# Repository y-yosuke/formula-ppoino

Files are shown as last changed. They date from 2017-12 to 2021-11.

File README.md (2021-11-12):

# formula-ppoino
- 2000年代前半ぐらいのフォーミュラカーっぽい2人乗りのクルマ
- A side-by-side two-seater car of the early 2000s formula style

# License
- クリエイティブ・コモンズ 4.0（表示/ BY ）で公開・共有しています．[Creative Commons 4.0 (BY)](https://creativecommons.org/licenses/by/4.0/)



# Contact
- Email: ppoino.cars.yy[a-t]gmail.com

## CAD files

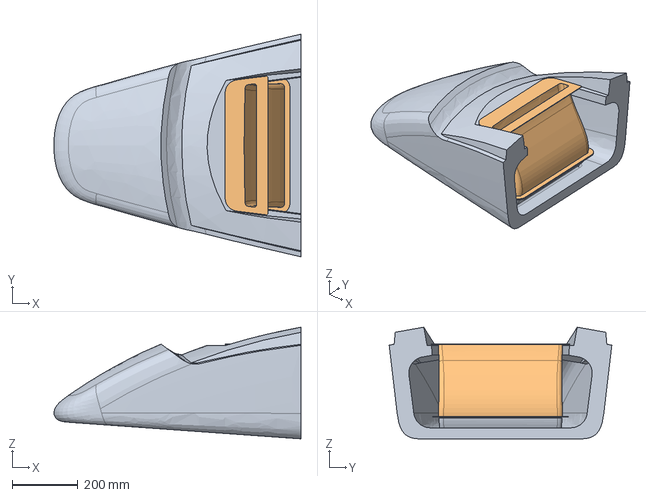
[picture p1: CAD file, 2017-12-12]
models/fp_nose_cone_assy.stp
749.1 x 675.3 x 338.7 mm

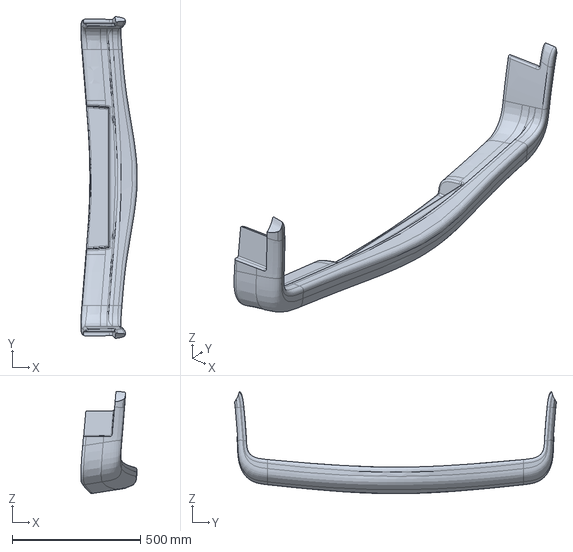
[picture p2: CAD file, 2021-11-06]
models/fp_rr_bumper.stp
220.4 x 1256.1 x 399.2 mm

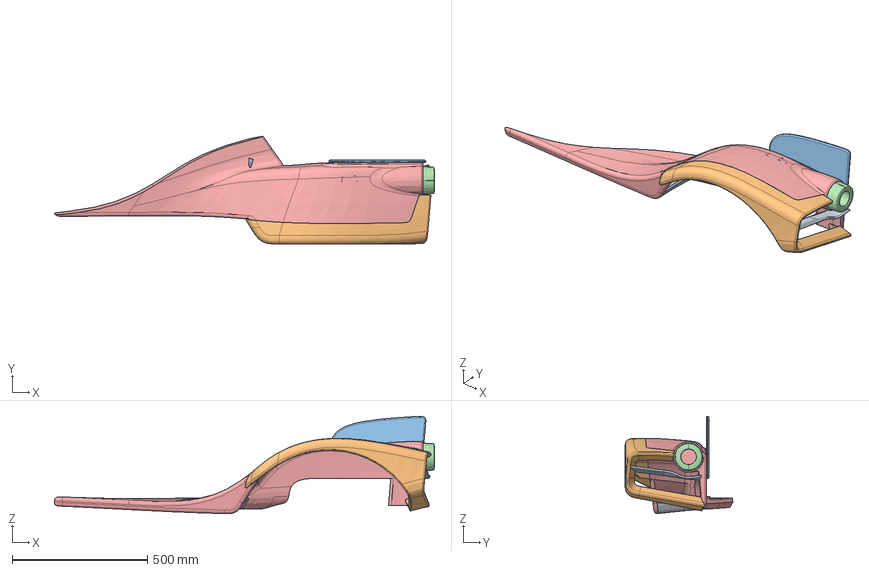
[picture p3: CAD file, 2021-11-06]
models/fp_rr_fender.stp
1404.7 x 398.4 x 359.8 mm

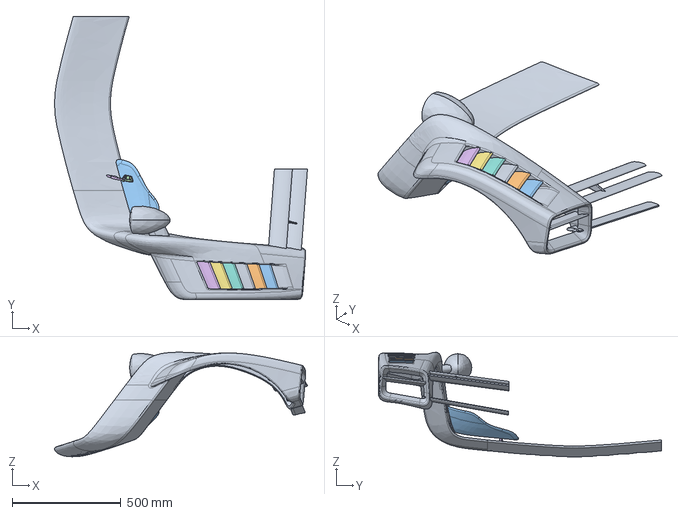
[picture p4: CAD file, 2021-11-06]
models/fp_fr_fender.stp
1161.1 x 1300.0 x 480.1 mm

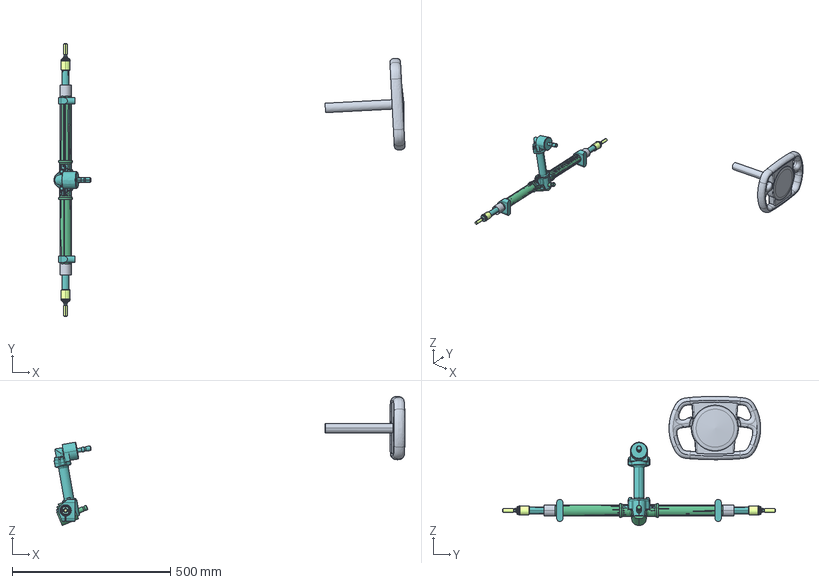
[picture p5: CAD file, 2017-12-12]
models/fp_steering_sys.stp
1108.2 x 862.0 x 407.7 mm

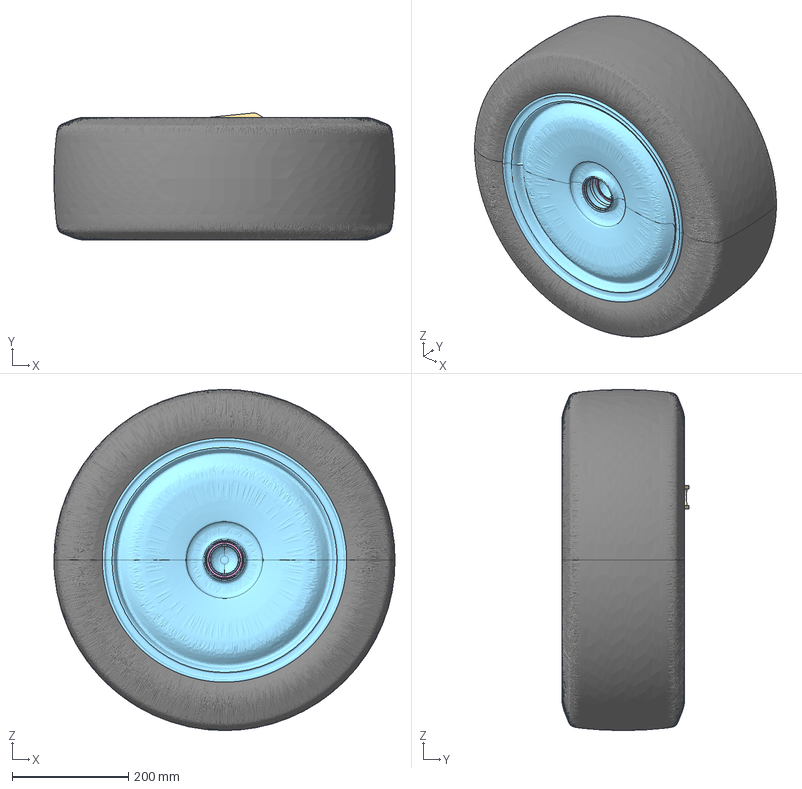
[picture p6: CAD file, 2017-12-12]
models/fp_fr_axle_sys.stp
586.7 x 218.5 x 587.0 mm

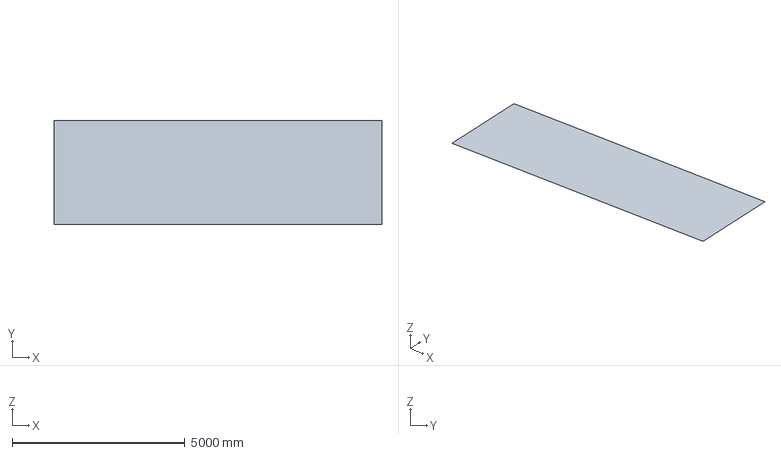
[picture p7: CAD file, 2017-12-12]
models/fp_environment.stp
9500.0 x 3000.0 x 0 mm

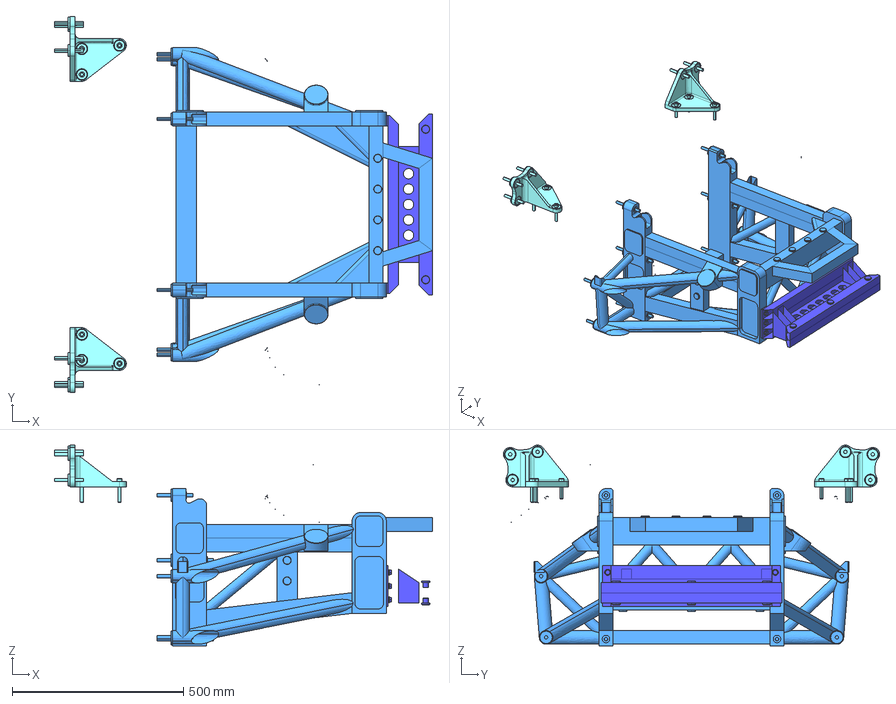
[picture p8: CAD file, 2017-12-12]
models/fp_rr_frame_sys.stp
1105.0 x 1100.0 x 587.0 mm

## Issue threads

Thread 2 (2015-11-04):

EV Module

y-yosuke, 2015-11-04:
ppoino-cars の formula-ppoino にある EV 関連の話のつづき．
https://github.com/y-yosuke/ppoino-cars/issues/4

y-yosuke, 2015-11-04:
formula-ppoino だけではなくて他の作りたいクルマでも利用できるものにしたい．

y-yosuke, 2015-11-11:
【メモ】
SiC半導体インバータの利点
https://www.youtube.com/watch?v=hzS-GOyyhTQ

y-yosuke, 2015-11-11:
【メモ】
Zytek Motors and Inverters / Mugen Honda CR-Z?
http://www.zytekautomotive.co.uk/products/electric-engines/
（あまり仕様的にはフィットしなそうだけど...）

y-yosuke, 2015-11-11:
おっと，YASA Motors に新しい P400 という製品が加わっている．
http://www.yasamotors.com/products/
http://www.yasamotors.com/products/p400_series/

y-yosuke, 2015-11-11:
YASA Motors - Patent Drawings
http://www.google.com/patents/US20130147291

y-yosuke, 2015-11-25:
【メモ】
乗用車やバスなどの商用車のモータ・インバータ・ビークルコントロールユニット
http://tm4.com/products/

y-yosuke, 2015-11-25:
【メモ】
シーメンス Siemens - SIVETEC モータ・インバータ・コントロールユニット
http://w3.siemens.com/topics/global/en/electromobility/Pages/powertrain-ecar.aspx

y-yosuke, 2015-11-25:
Tesla Roadster のバッテリー構造
http://www.teslamotorsclub.com/showthread.php/3810-Roadster-battery-%28ESS%29

y-yosuke, 2015-11-27:
理想的なインバータ・モータ統合モジュール
YASA 750 x2 x2 だったらこんな感じ．
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

y-yosuke, 2015-12-21:
Nissan Leaf NISMO RC が載っている MotorFan Illustrated Vol.58［Lite版］が ￥0 になってます．
http://3a.as-books.jp/books/info.php?no=MFI20110716
（紙版より企画を一部抜粋しての提供）

y-yosuke, 2015-12-24:
Formula-e - NEXTEV TCR Formula E 001 (2015-2016) に使われている？？？
http://www.gkn.com/driveline/our-solutions/edrive-systems/documents/datasheets/af-130-tech-sheet-v13.pdf

y-yosuke, 2015-12-24:
Formula-e のバッテリーは

容量 | 28kWh
----|----
出力 | 200kW
----|----
セル重量 | 200kg
----|----
バッテリーモジュール全体重量 | 345kg
とのこと．
「Motor Fan illustrated特別編集 Motorsportのテクノロジー 2015-2016 電子版」より
http://3a.as-books.jp/books/info.php?no=MFS20151224

y-yosuke, 2015-12-24:
Formula-e のバッテリーモジュール結構重いな．
あと F-1 もドライバ込み最低重量 702kg も今はあるのか... 500kg は遠き昔となりにけり．

emijah, 2016-01-08:
安全性に関してうるさくなりましたからね。重量をある程度上げないとドライバを守るのは難しいのかもしれませんね。

y-yosuke, 2016-01-08:
F1のレギュレーションの変遷のまとめを見ると
ざっくりと 620kg ぐらいまでは安全性の確保のため
700kg への変化は駆動系の複雑化のように見受けられます．
http://matome.naver.jp/odai/2134296850068589401

y-yosuke, 2016-01-08:
VW マイクロバスコンセプトカー BUDD-e
  - 蓄電容量101kWh
  - 4輪駆動
  - 最高速150km/h
  - 最大600kmの走行可能

http://response.jp/article/2016/01/06/267337.html

スペックは実走値なのか？ コンセプトとしてはこの値ということなのか？

y-yosuke, 2016-01-08:
Audi e-tron quattro concept

- 4輪適宜駆動
- 3モーター
  - 合計最大出力 370kW
  - 最大トルク 500Nm
- バッテリー容量 95kWh
- 最長航続距離 500km

http://car.watch.impress.co.jp/docs/event_repo/ces2016/20160108_738120.html

大きめの乗用車だと 100kW 前後が当たり前になってくるのかな．

emijah, 2016-01-13:
Teslaってスペック出ていますよね？ Xとかそれなりのモータが積まれていそう

y-yosuke, 2016-01-13:
https://en.wikipedia.org/wiki/Tesla_Model_X#Specifications

emijah, 2016-01-13:
３８６kWか568kWの２バージョンですね

y-yosuke, 2016-02-19:
日立造船 : 耐久性と安全性を向上させた全固体リチウムイオン二次電池を開発～低温から高温まで動作可能かつ長寿命～
http://www.hitachizosen.co.jp/news/2016/02/002027.html
（寸法と使用可能温度以外の仕様が発表されていない）

y-yosuke, 2016-02-20:
昨年の秋ぐらいに SiCインバータの回路モジュールのサンプル出荷が始まったはずなんだけど...
製品のカタチをなすのにはまだ時間がかかるということなのかな？
（続報はどこかにありましたか？？？）

y-yosuke, 2016-03-15:
【参考】Torque vectoring の話など
Mercedes SLS Electric Drive. Can Volts Ever Match Pistons? - /CHRIS HARRIS ON CARS
https://www.youtube.com/watch?v=IElqf-FCMs8

y-yosuke, 2016-03-18:
わーぉ Ariel Atom が電気自動車になっとるー
http://www.wrightspeed.com/about/x1/

y-yosuke, 2016-03-18:
drayson racing の YASA 750 は冷却の配管を削り物の部品で置き換えて高さを抑えている．
http://speedhunters-wp-production.s3.amazonaws.com/wp-content/uploads/2013/12/06200010/Drayson_Racing_Lola_EV-15-1200x800.jpg
http://www.speedhunters.com/2013/12/high-voltage-assault-battery/

y-yosuke, 2016-03-22:
超イオン伝導体を発見し全固体セラミックス電池を開発―高出力・大容量で次世代蓄電デバイスの最有力候補に― 東京工業大学
http://www.titech.ac.jp/news/2016/033800.html

emijah, 2016-03-22:
@y-yosuke 出てくるのに少なくとも５年かかりそうなんですかね？

y-yosuke, 2016-03-22:
「5年」というのはどこかに書いてありましたか？

emijah, 2016-03-23:
この記事はないですが、たいがい５〜１０年が多いので。探してみる必要がありますね。

y-yosuke, 2016-03-23:
YASA 750 2個使いだったら tm4 CO150シリーズ もありだな．
特にコネクタ類が1面だけに出ているのでレイアウト的に非常に助かる．
http://www.tm4.com/products/power-electronics/co150-traction-inverter/

（Rinehart Mosion Systems の PM100 や PM150 シリーズは端子などが3面から出ていて難儀）

y-yosuke, 2016-03-28:
【参考資料】
SIP（戦略的イノベーション創造プログラム）
次世代パワーエレクトロニクス（どこでもパワエレ機器で豊かな省エネ社会）
研究開発計画
http://www8.cao.go.jp/cstp/gaiyo/sip/keikaku/2_pawaere.pdf

y-yosuke, 2016-03-29:
全固体電池、10年飛び越し（2015.02.19の記事）
http://techon.nikkeibp.co.jp/article/MAG/20150205/402627/?rt=nocnt
Seeo社は "300Wh/kgの電池パックを2017年に出荷予定" / "350〜400Wh/Kgの実現にもメド" とのこと．

emijah, 2016-03-29:
500kmくらい走れないと遠出をする気にはあまりならないっすからね

y-yosuke, 2016-03-31:
【参考】日立造船が全固体リチウムイオン電池を開発、車載用に2020年に製品化
http://monoist.atmarkit.co.jp/mn/articles/1603/04/news052.html

y-yosuke, 2016-04-29:
電池だけでも 200kg ほどになりそうなバッテリーモジュールの設置に関して思案．

1. 単体で成立するバッテリーボックス（ストレスメンバー）に電池を組み込む
2. モノコック後部を長め（+250mm）にしてその中に直接何分割かした電池子モジュールを組み込む
3. モノコック後部を長め（+250mm）にしてさらにバッテリーボックスも単体モジュール化（非ストレスメンバー）

　　　＊下に各方式の長所・短所を列挙

今のところ私が一番良いと考えているのは 1. の

「単体で成立するバッテリーボックス（ストレスメンバー）に電池を組み込む」

が構成としてシンプルで他車種への応用が高く良いと思っていて，
それでレイアウト・設計を進めている．
（他車種への応用性の高さは妄想工学的に吉☆）

単体バッテリーボックス（ストレスメンバー）レイアウトの図
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

-----

1. 単体バッテリーボックス（ストレスメンバー）に電池を組み込み
  - 長所
    - EV後部駆動システムとして完全なモジュール化により他車種への応用がシンプルに
    - バッテリー不具合時にバッテリーボックス全体の交換が容易
  - 短所
    - バッテリーボックスにした場合にはそれも人間の乗る方のモノコックと同等の剛性・強度が必要となりコスト増
      - リチウムポリマー電池の事故時の発火の防止
      - ストレスメンバーとして
    - モノコックとリアフレームが直接締結されないことによる剛性低下

2. 長モノコック（+250mm）内に電池を直接設置
  - 長所
    - モノコックとリアフレームが直接締結されることによる剛性向上
    - モノコック構造体が1つで済むのでコスト減？
    - 重量最小？
  - 短所
    - 他車種にてこのシステムを利用しようとした場合に別途バッテリーの設置方法の設計が必要
    - 不具合時にバッテリーを交換するときに各バッテリ子モジュールを外す必要あり
      - 公道走るだけっだったらこれでも十分か？
      - レースに使うことを考えると不十分か？
    - モノコックが長くなることでラジエタパイプの通しどころの自由度が低い
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
y-yosuke, 2017-01-12:
Formula-e のバッテリーの生産元？
http://www.xaltenergy.com/index.php/industries/automotive-transportation.html

y-yosuke, 2017-01-12:
18650 Cells で Tesla Roadster 的レイアウトをしてみた．
一応，水冷パイプの空間も残しているつもりで 2540 cells になった．

- 諸元
  - 電圧 : 3.60V
  - 容量 : 3400mAh
  - 重量 : 48 g

とすると...

- 2540 x 3.6 [V] x 3.4 [Ah] = 31089.6 [Wh] = 31.1 [kWh]
- 2540 x 48 [g] = 121920 [g] = 122 [kg]

となる．円筒形の方がエネルギ密度が高いのか？ Cell を小さくするとエネルギ密度を高くできるのか？
また，バッテリボックスの形に合わせてレイアウトも可能なので，そう言ったところにも優位性がありそう．しかし組立は大変そう．

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

emijah, 2017-01-12:
組立やすさは、どういうバスバーを使って電力を外に出すかで決まりそうですね。

2017年1月12日 15:05 Yosuke Yamamoto <notifications@github.com>:

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

y-yosuke, 2017-01-12:
XALT Energy によると Formula-e は XALT 53Ah high energy (HE) lithium ion cells を使用しているとのこと．
http://www.xaltenergy.com/index.php/automotive-transportation.html
http://www.xaltenergy.com/index.php/solutions/technology/cells.html
http://www.xaltenergy.com/images/pdfs/datasheets/XE_Data_53HE_Updated.pdf

y-yosuke, 2017-01-12:
McLaren P1 のロウ付け（salt bath dip brazing）ものの Cell Module も凄いな．
http://www.invetr.com/control-and-electronics/energy-storage-system
http://www.invetr.com/uploads/2/1/8/2/21829402/1635370_orig.jpg

y-yosuke, 2017-01-12:
@emijah
Tesla Roadster は下記リンク先のポストにある画像のように Cell を Module 化しています．
Module 化した後は簡単ですが Module 化するところが大変そうです．
https://teslamotorsclub.com/tmc/threads/roadster-battery-ess.3810/#post-61701

y-yosuke, 2017-01-12:
Li-Ion だったらどれも同じようなものかな．
HV用ハイパワーとEV用ハイエナジーの違いぐらいか．
原理は一緒だしな．

y-yosuke, 2017-01-12:
http://kokam.com/cell/ も XALT と同じようなパウチを作っているようだけど同じような性能．

y-yosuke, 2017-01-12:
Samsung SDI や LG Chem はいろいろと使われているようだけど大口顧客相手でカスタマイズしているためかバッテリの仕様が出ていない．

y-yosuke, 2017-01-16:
ＥＶ・ＨＥＶ 駆動システム技術展
http://www.evjapan.jp/
2017年1月18日［水］～ 20日［金］ 10:00～18:00 (最終日のみ17時まで)

「フォーミュラE」用インバータ改良前後の2種を展示
http://www.rohm.co.jp/web/japan/carele

y-yosuke, 2017-01-16:
ロボデックスと同時開催とのこと．→ EV・HEV 駆動システム技術展

y-yosuke, 2017-02-03:
日刊工業新聞2017年2月2日 ショート・発火しにくい、リチウム電池。産総研が開発
http://newswitch.jp/p/7813
"医療機器に使うバッテリーなどへの応用が期待できる。企業と連携し、２０２０年頃までの実用化を目指す。"

y-yosuke, 2017-02-07:
[Topic] ホンダと日立オートモティブ、ＥＶモーターで新会社
http://www.nikkei.com/article/DGXLASDZ07H9D_X00C17A2MM0000/?dg=1&nf=1

y-yosuke, 2017-02-07:
Renault ZOE の Battery は LG Chem らしい．
http://insideevs.com/renault-zoe-r240-battery-capacity-23-3-kwh-usable-25-92-kwh-total/

y-yosuke, 2017-02-15:
Aston Martin AM-RB 001 to use Cosworth V12 and Ricardo gearbox
Partners for upcoming hypercar also include Multimac for the MonoCell and Rimac for hybrid batteries
http://www.autocar.co.uk/car-news/new-cars/aston-martin-am-rb-001-use-cosworth-v12-and-ricardo-gearbox

y-yosuke, 2017-03-31:
ＥＶ充電時間を３分の１に　チャデモ協議会、機器規格改定
http://www.sankeibiz.jp/business/news/170331/bsa1703310500003-n1.htm
"自動車メーカーが今後投入する高出力バッテリー搭載モデルで利用"

y-yosuke, 2017-04-04:
日産 リーフ 次期型はバッテリー2倍で航続500kmへ…デザインもほぼ判明
http://response.jp/article/2017/04/03/293024.html
"次期型は60kWh"

y-yosuke, 2017-04-15:
formula-e のブレーキバランスなどの記述
http://serakota.blog.so-net.ne.jp/2014-09-12

y-yosuke, 2017-05-11:
2013年の記事では Detroit Electric が Kokam のバッテリーを使っていると書いてある．
http://openers.jp/article/17738

http://kokam.com/modulepack-ev/?PHPSESSID=526f764faa66caaa76d9bd1fd5078f6c

y-yosuke, 2017-05-11:
MG Energy Systems はうちのが Detroit Electric SP:01 に使われていると書いている．
何年の記載なのかは分らない．
http://www.mgenergysystems.eu/projects/sp-01-electric-sports-car-powered-by-mgs-battery/

y-yosuke, 2017-05-11:
とは言っても...
どこの電池だろうが今のところ基本スペックは似たり寄ったりなのであまり参考にはならない．

本当，電池は軽く・小さくなって欲しいんだけどな．

y-yosuke, 2017-05-11:
Rohm の SiC デバイスと formula-e への採用のプレゼン＠国際カーエレ2017
[ROHM]国際カーエレ2017 - xEVの進化に貢献するSiCパワーデバイス
https://www.youtube.com/watch?v=FT4z2pTzipE

y-yosuke, 2017-05-12:
[ScienceNews2017]全固体電池　次世代電池の有力候補（2017年5月12日配信）
https://www.youtube.com/watch?v=DVXGBz3mQUs

y-yosuke, 2017-05-23:
横浜で明日から（5月24〜27日）開催される「人とくるまのテクノロジー展2017 横浜」に
YASA Motors も出品すると昨年の9月のリリースには書いてある．
http://www.yasamotors.com/jsae-japan-may-25-27/

人とくるまのテクノロジー展2017横浜
http://expo.jsae.or.jp/

y-yosuke, 2017-05-23:
日程間違っとるな．2017年5月24日（水）〜26日（金）だな．

emijah, 2017-05-24:
行く予定です

2017-05-23 17:38 GMT+09:00 Yosuke Yamamoto <notifications@github.com>:

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

y-yosuke, 2017-05-24:
私は5月25日（木）午後あたりに「人とくるまのテクノロジー展2017横浜」へ行こうかと考えています．
一緒に行った方が良いようでしたら @emijah さんの都合に合わせることも出来ます．

y-yosuke, 2017-05-24:
日時共に変更可能です．

y-yosuke, 2017-05-24:
英国パビリオンにはインバータなどの SEVCON も記載されているな．
http://expo.jsae.or.jp/wp-content/uploads/2017/05/y2017name.pdf

emijah, 2017-05-24:
メールします。

2017年5月24日 9:51 Yosuke Yamamoto <notifications@github.com>:

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

y-yosuke, 2017-05-24:
YASA Motors は三相ケーブルの出す方向を変更可能かを聞きたい．
営業の人だけかな．営業の人でも話しぐらい聞いてくれるかな？

emijah, 2017-05-24:
了解です

2017-05-24 11:21 GMT+09:00 Yosuke Yamamoto <notifications@github.com>:

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

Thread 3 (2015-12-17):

設計 TODO

y-yosuke, 2015-12-17:
- [] サスペンションジオメトリの検討・決定
- [] モノコック後端位置と電池モジュールケーシングの再検討
- [] Rr フレームの設計
- [] Fr フェンダーの面をきれいに

y-yosuke, 2016-02-12:
ヘッドライトはこれで良い気がしてきた...
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

y-yosuke, 2016-02-12:
（空力...）

emijah, 2016-02-12:
Rigid Industriesの棒みたいなLEDをウィンドスクリーンっぽいところの下に埋め込めない？
http://www.rigidindustries.com/led-lighting/91061h
とか

emijah, 2016-02-12:
ミラーに埋め込むのは無理ですかね？

y-yosuke, 2016-02-12:
埋め込むなら Fr Wing 〜 Fr Fender にかけてのところに縦目にしたいです．（従来案）

ミラー自体が無くなる可能性もなきにしもあらずですし，そこがヘッドライトとして光るのはデザイン上のバランスとしてちょっと嫌です．

丸目2つは「眼」としてのアイコン的に良いアクセントになる気がしたので試してみました．

感じ的にはルパンが乗っていたようなクラシックカーとか，
http://caxury.com/613
BMW 600 の Fr Bumper と Fr Light の組み合わせ的な感じとかの乗り．
https://ja.wikipedia.org/wiki/BMW%E3%83%BB600

y-yosuke, 2016-02-12:
ノーズコーン + 丸目2つ は Zagato Zanzara 的な．
http://www.zagato-cars.com/contents/en-us/d623_1969_Fiat_Zanzara_500_Zagato.html

y-yosuke, 2016-02-12:
（サーキットに行ったらフロントのナンバープレートとヘッドライトを外して下さい...）

emijah, 2016-02-12:
このZagatoのミラーの設置場所がすごいっすね

y-yosuke, 2016-02-12:
Zanzara いろいろと攻めてて，格好良くて，可愛くて，ベースが Fiat 500 で大好きです．

emijah, 2016-02-12:
500がベース！
500ってシャシーはフレームでしたっけ？

emijah, 2016-02-12:
Ghia Jollyができるということは下の車台が相当強いんですね

y-yosuke, 2016-02-12:
Fiat 500 はモノコック構造です．
https://ja.wikipedia.org/wiki/%E3%83%95%E3%82%A3%E3%82%A2%E3%83%83%E3%83%88%E3%83%BB500

Zanzara については NAVI 2009年10月号に Zagato の元チーフ・スタイリスト: エルコーレ・スパーダさんのインタビューが載っていて一部を引用しますと...

> 「...チンクエチェントの特徴的なインナーフェンダー（泥よけ）をそのまま外板に流用しつつ、そこにごくシンプルなボティワークを架装。同時にロッドの取りまわしをモディファイし、ステアリングの位置を下げ、本来、500の後席フットスペースに相当する箇所にドライバーのシートを置き、着座位置としました。...」

emijah, 2016-02-12:
そうなのか！
あそこまで切り落としてよくシャシーが持つなぁ。
しかし泥除けの形が今ではありえなくらい、いいですね。

y-yosuke, 2016-02-12:
バイクの 4.5インチ ぐらいのランプサイズに合わせて少し拡大（100mm → 120mm）して位置を調整したの図（ぱっちり眼）
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

y-yosuke, 2016-02-12:
フロントに丸要素を置くとするとリアにも丸要素が欲しくなる...
ブレーキランプを丸にするか...（既製品が使える）

y-yosuke, 2016-03-02:
Pull Request https://github.com/y-yosuke/formula-ppoino/pull/4 で出したデータのキャプチャ（一部 Hide）2枚

（やっぱ全体のデータをごっそり更新するのは違和感あるなー）

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

y-yosuke, 2016-03-02:
ヘッドライトとブレーキランプは 4インチ径 の汎用部品が使えないかとレイアウトしてみました．
方向指示器やポジショニングランプなどは未だデザインとかレイアウトとか出来ていないです．

フロントサスペンションはアッカーマン，逆アッカーマンのどちらでも行けそうな風に変更したのと，
ウィッシュボーンのモノコック側をモノコック内バルクヘッドで支えられるようにX方向を揃えたのが主な変更．

y-yosuke, 2016-03-11:
【メモ】
フロントのスプリング・ダンパー類をモノコックの内側に設置するとレイアウト的には色々と優位な天はあるものの，事故になった時にそれらが搭乗者を傷つける危険性があるのでモノコックの外側にそれらは設置する．
（何度も自分の中で同じ結論に至っているようなのでメモ）

y-yosuke, 2016-03-31:
2016年3月末時点でのデータを コミット，プッシュ，プルリクエスト，マージしました．
https://github.com/y-yosuke/formula-ppoino/pull/5

y-yosuke, 2016-04-16:
【メモ】
形や大きさから F3 を設計しているような気になるけど
EV の場合はバッテリーモジュールを 300kg ぐらいで考えていて
そうすると搭乗者も含むと車体全体で 1000kg ほどになりそうなので
どちらかと言うと GT に近い感覚で設計した方が良い気がする．

y-yosuke, 2016-05-01:
4月作業分のコミット・プルリクエスト・マージを行いました．
https://github.com/y-yosuke/formula-ppoino/pull/6

y-yosuke, 2016-05-04:
Wing Flap Adjuster
http://www.primusracingparts.com/wing-flap-adjuster_p_292.html

y-yosuke, 2016-05-13:
リアのコンビネーションランプはこの組み合わせで良い気がする．

IPF - LED TAIL & STOP TL-01
LED 丸形テール＆ストップランプ TL-01
https://www.ipf.co.jp/products/tl01.html

IPF - LED BLINKER UNIT - FRONT : TL-02WUF / REAR : TL-02WUR
丸形LED ウィンカー　フロント:TL-02WUF / リア：TL-02WUR
https://www.ipf.co.jp/products/tl01WU.html

y-yosuke, 2016-05-14:
リアコンビランプはこんな感じ．
IPF - LED TAIL & STOP, Blinker Unit

ちょっとランプにかかるスリーブがあっても良いかも．

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

y-yosuke, 2016-05-29:
5月分のコミット・プルリクエスト・マージだん．
https://github.com/y-yosuke/formula-ppoino/pull/7

y-yosuke, 2016-05-29:
全体のサイドビュー
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

y-yosuke, 2016-06-12:
やはりリアのナンバープレートは車体フレームにつけるもんなんかー
http://minkara.carview.co.jp/userid/1769468/car/1309784/2583849/4/note.aspx#title

封印もあるし，むやみに外したり出来ないようにしているんだろうけど...
そーなると formula-ppoino の場合は登録的にはリアサブフレームが車両本体のようになるのかな？

y-yosuke, 2016-06-14:
HONDA VFR800P のウィンカーが大きいので正面視で 20cm^2 を越えていたら使えそうなのだが...
とっくに生産終了か...
https://ja.wikipedia.org/wiki/%E3%83%95%E3%82%A1%E3%82%A4%E3%83%AB:Japanese_HONDA_VFR800P_police_motorcycle.jpg

emijah, 2016-06-14:
これはどうですかね？
https://www.amazon.co.jp/gp/aw/d/B0174D9LR8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

2016年6月14日(火) 18:03 Yosuke Yamamoto <notifications@github.com>:

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

y-yosuke, 2016-06-14:
おそらく 20cm^2 以下ですね．
バイクの汎用品でも探しているのですが大体は車の規格に満たない大きさで不採用になります．

y-yosuke, 2016-06-14:
【メモ】20cm^2 を満たす寸法とは
- 7cm x 3cm = 21cm^2
- 5cm x 4cm = 20cm^2
- ( 5.5cm / 2 )^2  x 3.14 = 23.7cm^2

方向指示器の法規（大きさなど）
http://www.mlit.go.jp/common/000187504.pdf

y-yosuke, 2016-06-14:
Ninja1000 デイライト内蔵LEDウインカー
http://www.bosscom.jp/product/ninja1000/
大きそうだけど寸法が書いていない．そしてべらぼーに高い (T_T)

y-yosuke, 2016-06-14:
ドライブレコーダーはバイク用のが良さげ．例えばこんなの ↓
https://www.yupiteru.co.jp/products/bike_drive_recorder/bdr-2wifi/spec.html

そして補助制動灯の設置（高さ850mm以上）とカメラマウントを兼ね備えた左右のロールバーを繋ぐ位置の整流ウィング風ステイを設計中．
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

emijah, 2016-06-14:
これいいっすね！
ZZRのカウル用のウィンカーって確かでかかったような

2016年6月14日 18:48 Yosuke Yamamoto <notifications@github.com>:

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

y-yosuke, 2016-06-14:
ZZRのウィンカーも大きくてもしかしたらOKなのかも？と思ったのですが
ウィンカーの部品をWEB見たときに売切れだったので
カワサキのサイトを見たら現行車種になかったので除外していました．
http://www.kawasaki-motors.com/mc/lineup/

現行車種でなくても部品の在庫さえあれば検討対象になるのですが
バイクの部品というのは廃番後も長く在庫しているものなのでしょうか？

y-yosuke, 2016-06-14:
もしくはフレキシブルLEDチューブライト的な
http://ja.aliexpress.com/store/product/2pcs-60cm-DRL-Flexible-LED-Tube-Strip-Style-Daytime-Running-Lights-Tear-Strip-Car-Headlight-Turn/121101_32362504399.html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

emijah, 2016-06-14:
こっちの方がいいかも

2016年6月14日(火) 22:00 Yosuke Yamamoto <notifications@github.com>:

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

y-yosuke, 2016-06-21:
ちょっと上がってた集中力が落ちたので6月分としては早めだけど Commit, Push, PR and Merge．
変更の詳細と全体のスクリーンショットを Pull Request 8 に載せておきました．
https://github.com/y-yosuke/formula-ppoino/pull/8

y-yosuke, 2016-06-27:
スチール（SCM？）版 Roll Hoop
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

y-yosuke, 2016-07-07:
Bulge - Damper / Fr Suspension
Environment Map（Space Needle）
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

y-yosuke, 2016-07-21:
モノコックの足下部分の面を水平にそして少し上げようと考えたが
そうすると車両法規のシートの寸法 40cm x 40cm をクリアするのが難しくなりそうだ．

水平面に投影したときに 400mm x 400mm 四角となるような座面（仮）
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

座面とモノコック，ドライバとの隙間の関係．下の条件を考えると Fillet 部分が無いと厳しい．
- モノコック厚さ 25 〜 30mm
- シートのクッション厚さ ?0mm ？
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

y-yosuke, 2016-08-20:
さて CFD が SimScale で出来たのでフロント周りのエアロデバイスばかりこのところ試していた #12 が目処も着きそうなのでリアもと思うところだが Xtrac のギアボックスを採用したいのでレイアウトとのものから変更で，フレームはもちろん，サスペンションジオメトリも変わるかもの状態．

Xtrac のギアボックスの CAD データがあれば最も良いが，せめて外径寸法の載った図面がないかな．
でないとレイアウトが進まないぞ．

emijah, 2016-08-22:
聞いてみましょうか？

2016年8月21日 1:51 Yosuke Yamamoto <notifications@github.com>:

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

y-yosuke, 2016-08-22:
Xtrac にですか？ ぜひお願いします．

emijah, 2016-08-22:
了解です。

2016-08-22 13:31 GMT+09:00 Yosuke Yamamoto <notifications@github.com>:

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

y-yosuke, 2016-08-22:
ちなみに画像から想像モデリング https://github.com/y-yosuke/formula-ppoino/issues/2#issuecomment-231523173 したのを横から見た図．（ギアボックス→紫線）
コンパクトであって欲しい願望がモデリングには入っていそうなので実際はもう少し大きいようなきがする．
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

y-yosuke, 2016-08-23:
#15 で最新のデータをマージしました．

y-yosuke, 2016-08-31:
【メモ】
Technical Regulation などの PDF にある点群の座標データ（テキスト）から Rhinoceros に点群をインポートする手順

1. テキストデータが含まれる PDF ファイルを保存
2. PDF ファイルを Adobe Reader で開いて テキスト形式（*.txt）で保存
3. 必要な座標が描いてある部分のみのテキストファイルを作成
4. LibreOffice でテキストファイルを開く（適宜セルのセパレート書式を指定）
5. LibreOffice にて CSV 形式（*.csv）で保存
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
y-yosuke, 2017-03-30:
ただタイヤの設置面でのジオメトリ変化を見ていないのでそこは要チェック項目です．

y-yosuke, 2017-04-03:
Caterham F1 のリアアップライト
https://pbs.twimg.com/media/Ch9E-tQWEAIzB06.jpg:large

結構小さい玉のベアリングを使っているんだな．

y-yosuke, 2017-04-03:
Formula e のモノコック
http://current-e.com/wp-content/uploads/2014/05/Carbon-fibre-tub.jpeg

サスペンションの取付け点は大きめのインサートでアウタースキンごと切削しているのか．
そんなんだったけか？ もう記憶が...

y-yosuke, 2017-04-07:
消化器は Foam ではなく Gas の方で良いのかな？ 公道的にもサーキット的にも．

emijah, 2017-04-07:
消火の際、公道であればFoamを使われてしまうんじゃないですかね？ガスは消えてしまうので、再び燃え出す可能性はありませんかね？

2017-04-07 18:42 GMT+09:00 Yosuke Yamamoto <notifications@github.com>:

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

y-yosuke, 2017-04-07:
車載定置の消化器を選定するにあたり，どちらかな？ どちらだったかな？ の視点においては？

Foam と Gas のどちらも FIA 認定の品があるので．
http://www.f-e-v.co.uk/products/

電気自動車的には Gas の方が良いのかな？ Foam は導電性はどうなんでしょう？
粉末はABC粉末があるので電気火災にも対応していますが．

他所の人は Gas じゃなくて Foam か粉末かの消化器を使うのは多分そうですね．

y-yosuke, 2017-04-07:
日本語の Wikipedia の消火器のページを見る限りにおいては「化学泡」「機械泡」のどちらも電気火災には対応していないな．
https://ja.wikipedia.org/wiki/%E6%B6%88%E7%81%AB%E5%99%A8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

そうすると Gas または 粉末 の消火器ということになるのかな？

emijah, 2017-04-07:
そういうことですね。事故ったテスラの写真を見ると粉末を使っているケースが多いかもしれませんね。

2017年4月7日 19:12 Yosuke Yamamoto <notifications@github.com>:

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

y-yosuke, 2017-04-07:
LEAF レスキュー時の取り扱い
http://www.nissan-global.com/JP/DOCUMENT/PDF/SAFETY/RESCUE/RESCUE_LEAF02.pdf

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

まじか．大量に水を使えたら水を使うんか!!!

y-yosuke, 2017-04-07:
FEV - FESG1700E (FIA) : Capacity = 1.7kg
http://www.f-e-v.co.uk/product/fesg1700e-fia/

FEV - FESG1800E (FIA) : Capacity = 1.8kg も同じ大きさなんだな．本当か？
http://www.f-e-v.co.uk/product/fesg1800e/

で，なんか小さいような...
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

y-yosuke, 2017-04-07:
FEV を扱っている日本の販売店のサイトを見るとフォームタイプでも電気火災に対応していると書いてある．対応さえしていればガス・フォームでも大丈夫なのか．
http://irs.co.jp/fire_ex/fev-system/

y-yosuke, 2017-04-08:
モノコックのバルクヘッド
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

emijah, 2017-04-11:
なるほど、ショートするところはショートさせて一気に冷やすということなんでしょうね。

2017年4月7日 20:10 Yosuke Yamamoto <notifications@github.com>:

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

y-yosuke, 2017-04-12:
Rr Tire に考えていた Yokohama Advan S-drive の 225/45R16 が英語のサイトからも消えてるなぁ．
https://www.yokohamatire.com/tires/s-drive

他のメーカでも 225/45R16 はサーキット用のような溝のものしかなくてウェットで心配だ．

215/45R16 はあるようだからそっちにするか...
http://www.y-yokohama.com/product/tire/sdrive/

y-yosuke, 2017-04-12:
Toyo Tire には Rr : 225/45R16 も Fr : 205/50R15 もあるからそれでいいか．
  - Toyo Tire - Proxes T1R
    - http://toyotires.jp/size/pxt1r.html

y-yosuke, 2017-04-13:
NASボルトを使っていたところもメートルねじにしたいなぁ．

emijah, 2017-04-13:
今やメートルにしない理由はないんじゃないですかね？

2017-04-13 14:47 GMT+09:00 Yosuke Yamamoto <notifications@github.com>:

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

y-yosuke, 2017-04-13:
NASボルトに相当するメートルねじを探しているのですがなかなか適当なものが見つからないです．

- 適度に短いネジ部
- 精度の高い非ネジ部

設計したらそれで済むのですが，既製品を使うにこしたことはないので探し中です．

y-yosuke, 2017-04-13:
NASボルトも直径の精度的には 0.01 インチぐらいなので 0.254 mm とそんなに精度は高くないのか．

あとは強度とか耐食性かな？

y-yosuke, 2017-04-13:
やはり NAS Bolt に代わるメートルねじが無いらしい．
NAS Bolt とインチねじはサスペンションで使用するということにしておく．
何か良いものがあればまた考える．

y-yosuke, 2017-04-15:
Ferrari F300 Cutaway
https://primotipo.files.wordpress.com/2015/01/matthes-f300-cutaway.jpg
バルクヘッドなど

y-yosuke, 2017-04-18:
とりあえず置いてみるの図
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

y-yosuke, 2017-04-26:
- バンプステア（フロント）
  - 50mm バンプ時
    - 約 0.05 deg トーアウト
      - 50,000 mm x sin( 0.05 deg ) = 43.6 mm
  - 50mm リバウンド時
    - 約 0.15 deg トーイン
      - 50,000 mm x sin( 0.15 deg ) = 130.9 mm

両者の途中はまだ描画・計算していない．
まぁ，バンプしっぱなし，リバウンドしっぱなしはまず無いとはいえ，どんなもんなんだろうか？

y-yosuke, 2017-04-26:
このページのグラフを見ると，まぁ少ない方かな？といえる？？？
http://www.fiero.nl/cgi-bin/fiero/pdaShowThread.cgi?forum=3&thread=000116&page=48

y-yosuke, 2017-05-06:
Suspension Geometry
http://www.car-engineer.com/suspension-design-definitions-and-effects-on-vehicle-behavior/

y-yosuke, 2017-05-06:
「いっけなーい☆ キャスター角 15°ってつき過ぎ?! 10° 10°」（パンを咥えて走る少女

emijah, 2017-05-10:
suspensionの本を引っぱり出して読まないといけないくらい忘れているぅ

2017-05-07 0:42 GMT+09:00 Yosuke Yamamoto <notifications@github.com>:

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

y-yosuke, 2017-05-25:
See y-yosuke/ppoino-cars#18

y-yosuke, 2017-05-26:
この丸形ヘッドライトは 5.75 inch で High/Low・ポジショニングランプ・ターンシグナル込みのLEDランプで良さげな気もする．アリババだけど．
https://www.alibaba.com/product-detail/-Hot-Sale-5-75-inch_60338811974.html

そしてメーカのサイトには当該商品がラインナップに無い不安さ．
http://wukmaled.en.e-cantonfair.com/china-supplier/344104.html

y-yosuke, 2017-05-26:
あとバイク用とあるからターンシグナルの面積が足りない可能性もあるな．

y-yosuke, 2017-05-26:
5.75" Round Headlights with Turn Signal
https://www.jwspeaker.com/products/led-headlight-model-8631-evolution/

4輪用だし図面もあるしこれが良いかな．

y-yosuke, 2017-05-26:
5.75" Round Headlights with Turn Signal
https://www.jwspeaker.com/products/led-headlight-model-8631-evolution/

4輪用だし図面もあるしこれが良いかな．

y-yosuke, 2017-05-26:
あとはチューブ状の LED Turn Signal（前にも似たようなもののリンクを張ったけど）
http://www.xkglow.com/XKGLOW_Sequential_Switchback_Strips_for_Headlight_p/xk043001.htm

y-yosuke, 2017-05-30:
直径 70mm Hi/Lo Headlight バイク用
http://www.protec-products.co.jp/products/lh/flh870/

y-yosuke, 2017-05-31:
JW Speaker 4.5" LED Headlights 8415 Evolution - High/Low
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

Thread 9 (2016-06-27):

エンジン駆動としたら

y-yosuke, 2016-06-27:
エンジン搭載の場合は使える適切なエンジン・ギアボックすがあるのか？

- 調達ができるか（試作・量産）
- 設計用のデータがあるか？
- 適切なギアボックスがあるか？

emijah, 2016-06-27:
F4から流用はできなさそうですか？（弱すぎ？）

2016年6月27日 17:29 Yosuke Yamamoto <notifications@github.com>:

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

y-yosuke, 2016-06-27:
せめて F3 と思うのですが... あと，エンジンの長さにもよりますがおそらくは横置きになります．
F3 などと比べるとモノコック後端からリア車軸までは短いので，
そして2人乗りの分，幅方向はあるのでなるべく重心を前にしたいので．

でも，PORSCHE 919 Hybrid の 2L V4 エンジンなんか短かったらNA使いで縦置き妄想☆
http://sportscar365.com/lemans/wec/porsche-reveals-first-photos-of-919-hybrid-engine/
http://www.tomorrowstechnician.com/porsches-le-mans-919-hybrid-turbo-four-cylinder-engine/

emijah, 2016-06-27:
昔のマッスルカーのようにギアボックスが後端から突き出ているというのは無しですかね？美的感覚からアウトかな

2016年6月27日 17:50 Yosuke Yamamoto <notifications@github.com>:

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

y-yosuke, 2016-06-27:
重心はなるべく前で

y-yosuke, 2016-06-27:
バイク用で V4 エンジンがあるか．（ギアボックスつながるのか？）

http://bike-lineage.jpn.org/yamaha/vmax/vmax.html
本当に 200馬力 出るのだろうか？

http://thekneeslider.com/is-the-motus-v4-baby-block-crate-engine-the-future-of-old-school-hot-rodding/
出力値を見つけられなかった．

y-yosuke, 2016-06-27:
まぁ，ドイツでは走れなくなるかもしれませんが...
"ドイツ政府、2030年までに全ての新車を無排気車にすることも検討中"
http://jp.autoblog.com/2016/06/25/germany-cars-emissions-free-2030/

emijah, 2016-06-27:
この会社のエンジンはどうですか？

2016-06-27 18:20 GMT+09:00 Yosuke Yamamoto <notifications@github.com>:

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

y-yosuke, 2016-06-27:
リンクなし？？？

emijah, 2016-06-27:
失礼
http://liquidpiston.com/

2016年6月27日(月) 18:39 Yosuke Yamamoto <notifications@github.com>:

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

y-yosuke, 2016-06-27:
Liquid Piston のはまだ大出力化に至ってないと私は認識していますが，どうなんでしょう？

ロータリーエンジンの1つだと思いますが，
一般論としてロータリーエンジンは同出力でも体積が小さくできるメリットがあります．

もしかしたら EV のレンジエクステンダーのように使うのもありかもしれません．

emijah, 2016-06-28:
http://liquidpiston.com/technology/x-engines-diesel/
を見ると40, 70HPは達せしていますが、確かにそれ以上の出力のものは見ませんね。

2016年6月27日 20:01 Yosuke Yamamoto <notifications@github.com>:

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

y-yosuke, 2016-09-16:
ひとまずクローズ

Closed 2016-09-16.

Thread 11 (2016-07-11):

CFD Simulation on SimScale

y-yosuke, 2016-07-11:
SimScale のアカウント（free）を取得したので CFD 用のモデルを作成中
https://github.com/y-yosuke/ppoino-cars/issues/8#issuecomment-230393780

【メモ】
- Scale 1:1
- カウル部一般厚 10mm
- とりあえずラジエタは素通り
- コクピットはメッシュ削減のため埋め気味で搭乗者も簡略化
- カウルのパーティングラインはメッシュ削減のため無しに
- フロントナンバープレートはまず無しで
- Frontal Area = 644554.461 (+/- 0.03) square millimeters (Half)
  - 2 x 64554.461 [mm^2] / 1000000 [mm^2/m^2] =  1.2891 [m^2]
    - ブロッケージを 5% とすると 1.2891 / 0.05 = 25.782 [m^2] → 5.08 [m] x 5.08 [m]

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

y-yosuke, 2016-07-12:
W(Half) : 3.0 [m] x H : 6.0 [m] x L : 30.0 [m] ( Blockage : 3.6 [%] )  だとこんな感じ．
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

y-yosuke, 2016-07-12:
SimScale にCADデータを上げた．これからメッシュ切りの手順を勉強する．
https://www.simscale.com/projects/yosukegb4/fp-023b/

y-yosuke, 2016-07-12:
あー External Flow にしたら Box は SimScale 側で設定できるのか．
とりあえずこのデータで Intrenal Flow として今メッシュ切り中．

y-yosuke, 2016-07-12:
データは STP で出力したけど Internal Flow としてメッシュ切るのなら STL の方が良いとかあるのかな？それも後々試そう．

y-yosuke, 2016-07-12:
automatic で fitness を very fine にしても粗い．フラップの隙間が潰れてる．
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

emijah, 2016-07-13:
うーん

2016-07-13 8:01 GMT+09:00 Yosuke Yamamoto <notifications@github.com>:

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

y-yosuke, 2016-07-13:
おそらく internal flow が原因だと今のところ考えていて external flow にしたらモデル周辺は細かく切って遠いところは粗く切るのではないかと想像しています．
今日それを試してみます．

y-yosuke, 2016-07-13:
あ，YASA 750 のバルジのモデルを入れてない．（ま，メッシュの練習だし...
あと，地面のメッシュは細かく切りたいな．

y-yosuke, 2016-07-13:
メッシュの切り方，丁寧に書いてあるわ
https://www.simscale.com/docs/content/tutorials/tutorial_frontwing.html

y-yosuke, 2016-07-13:
ところで SimScale の Core hours 3000 hours って月あたりの時間ということなのか？否か？
4 cores でフルで回したら 4 [core] x 24 [h] x 30 [day] = 2880 [h] で大体それぐらいの時間になるのだけど．

y-yosuke, 2016-07-13:
メッシュ粗さの件は internal / external ではなくて automatic / parametric の違いみたいだ．
parametric にして領域・面などによってメッシュの疎密を設定する．

y-yosuke, 2016-07-13:
良い感じになりもうした．
もう少し下流の粗いところを密にした方が良いような気もするが，まずこれでCFDにかけてみよう．
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

y-yosuke, 2016-07-13:
で，ノード数が 26109120 になったのだけどシミュレーション計算にかけたら
8 cores ではメモリが足りませんでした．となったので 32 cores で設定し直して再計算中．
それでも駄目だったらメッシュの削減をしなくてはならない．

y-yosuke, 2016-07-14:
32 cores にしてもメモリが足りないとのことでメッシュを粗く切っているところ．

y-yosuke, 2016-07-14:
【メモ】CADデータの受け渡し
- STEP
  - タイヤのような1つの面で大きく曲がっているものの形状の再現性が怪しい．
  - 単位もデータ内に持っているようで [mm] で出力しても [m] に自動的に換算されている．
  - インポートされた面はそれぞれ持って行かれるのでそのまま face set などにできる．
- STL
  - [mm] で出力したらそのままなので Geometry Operation で 0.001 乗算変換
  - インポートされた面は全体で1つの閉曲面として認識されるので Geometry Operation で切り分け角度指定での面分割が必要

emijah, 2016-07-14:
;_;)

2016年7月14日 16:57 Yosuke Yamamoto <notifications@github.com>:

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

y-yosuke, 2016-07-14:
スケール変換なども SimScale 側の core 占有が勿体ないと思ったら MeshLab で予め変換しておけば良い．

y-yosuke, 2016-07-14:
SimScale 上での STL の Surface splitting は Error が出て失敗したので STL は不採用．
よって，STEP の変になる面，具体的にはタイアの Surface を Knot に沿って分割して
SimScale に読み込んだときの質を確保．

y-yosuke, 2016-07-14:
IGES も試したがタイヤのサーフェスがおかしくなるのは STEP と同じで，
更には単位が着いてこないので 0.001 倍しないとならなく，
STEP に比べて良いところがないので不採用．

y-yosuke, 2016-07-15:
【作業メモ】
Fr Flap も SimScale 上の STEP での形状再現性が低かったので Rhinoceros にて Shrink Trimmed Surface を行って STEP エクスポートのし直し．

y-yosuke, 2016-07-15:
1つずつメッシュが正常に切れない問題をつぶしているところ．
- メッシュは曲率の大きさによって精度を分けることにより形状追従性と省メッシュを両立
  - ウィングの前後端は面を分けておく（Rhinoceros だったら Split）
  - いわゆるフィレットの部分のメッシュを細かく
- 面の交差が 90 deg を超えるようなところ？は面の続きがおかしくなり易いので注意
- Wind Screen のような薄いところは SimScale の Geometries -> [ CAD Data ] -> Topological Entity Sets で face set を作っておき Mesh Refinements で特に細かく設定
  - もしくは CAD File の時点で厚くしておく

y-yosuke, 2016-07-16:
もう12年ぐらい前の話だけど当時 SCRYU/Tetra でメッシュ切るのそんなに苦労した記憶がないのに何で？とぐぐったら SCRYU/Tetra の売りはメッシュ切りと当該ページには書いてある．そういうことなの？？？
http://www.cradle.co.jp/products/scryutetra.html

テトラメッシュでも切ってみるか...
（メッシュ切りのテストだけで 3000 core hours を使ってしまうのでは!? という恐怖... orz）

y-yosuke, 2016-07-16:
OpenFOAM の方から調べると blockMesh は薄い部分の表現が苦手なようだ．

y-yosuke, 2016-07-17:
external flow で Bounding Box と元の CAD Data の組み合わせで流体領域を形成するのだけれども，
どこかのメッシュ（フラップとフェンダーの交差部？かタイヤと地面の交差部？）が裏返ってしまって
領域が車体の内外両方になってしまう．

このため internal flow の CAD Data を再び使い，今回は "Hex-dominant automatic for internal flow (only CFD)" ではなく "Hex-dominant parametric (only CFD)" で良い感じにメッシュが切れないか試行中．

y-yosuke, 2016-07-17:
"Tetrahedral with layer refinements" でメッシュ切りを試したがエラーが出て切れなかった．
理由はわからないが，今回はこの方向の試行は中止かな．snappyHexMesh の方向でがんばる．

y-yosuke, 2016-07-17:
流体領域を CAD Data で形成しておいた方がおかしなことになりにくいようだ．

SimScale 上でライドハイト設定を変えてメッシュが生成されるのがベストだろうが，まともなメッシュが切れないようでは元も子もないので，手間は増えるが予め CAD で流域を形成したデータを複数使うのがセカンドベストかもしれない．

手間と言っても車体モデルを Transfer して流域の Box と Boolean をとるだけだけど．
更には厳密に言うとライドハイトによってサスペンションアームの形が変わるのでそう言った意味ではこれがベストなのかもしれない．
SimScale の CAD データは "Import from Onshape" の機能があるのでライドハイト変化などのパラメトリック要素は Onshape 上で処理をして流体領域を形成して一連のパターンを SimScale にてバッチ解析する作業の流れもありかも．

y-yosuke, 2016-07-17:
メッシュ良さげか!? これで解析に流せるかな．
https://www.simscale.com/workbench/?pid=4105619712994739995#tab_0-0
Meshes -> Mesh 1 2 2

Nodes (Points) 6,245,308 で大体目標値．

メッシュ全体（手前の面は Hide してる）
流域 Box の周辺が細かいのは勿体ないが CAD のエッジをメッシュに反映する設定 "Feature refinement" が CAD の Surface 全部にかける方法しかないため仕方ないか，というところ．
改めて見ると，車体後流部はもう少し長く，細かくしたいところだが...
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

メッシュ拡大
Flap と Wing の隙間が怪しいことになってる．改善したいところだが...
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

レイヤーの様子（3層）
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

領域はちゃんとしているようだ．
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

y-yosuke, 2016-07-17:
I think snappyHexMesh is not beautiful.

y-yosuke, 2016-07-17:
まだメモリーエラーが出るなぁ... (T_T)

y-yosuke, 2016-07-17:
やはりメッシュがおかしいような気がする．

SimScale の STEP/IGES → サーフェスメッシュの変換がおかしいのでいろいろな人の Project をみていたら，これ ↓ なんか STL で読み込んでいるのに複数ソリッドが存在している．
https://www.simscale.com/projects/pfernandez/perrinn_f1_v5/
ソリッド化した STL だとそれぞれの閉領域が1つのまとまりとして SimScale で認識されるらしい．

STL でもソリッド化というプロセスがあるらしく，それは FreeCAD で出来るらしい．
http://monoist.atmarkit.co.jp/mn/articles/1602/12/news011.html

ということで FreeCAD 氏に働いてもらっているところだが... 帰ってこない... orz

y-yosuke, 2016-07-17:
複数要素の STL データを SimScale にインポートするために試したことで駄目だったことリスト
- Rhinoceros から Binary でSTL出力する → 1つのオブジェクトになるのは変わらず
- 複数の STL ファイルを ZIP にまとめてアップロードする → 最初の1つの STL ファイルしか読み込まず

emijah, 2016-07-18:
うーん、互換性にまだ問題があるんですね

y-yosuke, 2016-07-18:
タイヤ＆ホイールを回さなければ STL でそのまま出来るようなのですが...

y-yosuke, 2016-07-18:
3000 core hours は1年あたりとのこと．すぐ使い切りそうだな．
"3000 core hours of computing power per year"
https://www.simscale.com/forum/t/simscale-plans-pricing/27827

y-yosuke, 2016-07-18:
STL で複数の領域があるデータを SimScale にアップロードする方法が分った．

SimScale のフォーラムに書いてあったのだがそれだけでは足りない部分が私の環境ではあったので Rhinoceros で STL 出力してから SimScale にアップロードするまでの手順を書いておく．

### 1 . STLファイルのエクスポート（ASCII）

Rhinoceros で分割して利用したいソリッド部分をそれぞれ **ASCII で STL 出力**する．
例えば，body, fl-wheel, fr-wheel, rl-wheel, rr-wheel などで分ける．

### 2 . STLファイル内の solid 名の変更

STLファイル内の solid の名称が全て OBJECT になっており，そのままだと SimScale で利用する際に区別がつかなく face の選択ができない．
そこで，各 STLファイル をテキストエディタなどで編集してファイルの冒頭と末尾にある次の行を編集して，各 solid が固有の名称を持つようにする．

＜変更前＞
```
solid OBJECT
...
endsolid OBJECT
```

＜変更後（例）＞
```
solid OBJECT2
...
endsolid OBJECT2
```

### 3 . STLファイルの結合
コマンドラインで次のように cat を実行して複数のSTLファイルを1つのSTLファイルに結合する．
```
cat 1.stl 2.stl 3.stl 4.stl 5.stl > fp-023b_cfd_combiled_rename-OBJECT.stl
```

### 4 . ZIP圧縮（必要ならば）
結合したSTLファイルが 300MB を超えるような場合はZIP圧縮をして 300MB 以下にする．
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
y-yosuke, 2016-07-21:
メッシュの数によって Coefficient の値は結構変わってくるようだ．

Coef. | 6,049,050 nodes | 7,278,072 nodes | Difference | Difference %
---|---|---|---|---
Cm | 0.1417 | 0.1355 | -0.006181 | -4.361
Cd | 0.5674 | 0.5555 | -0.01183 | -2.086
Cl | -0.1681 | -0.1540 | +0.01404 | +8.353
Cl(f) | 0.05766 | 0.05850 | +0.0008400 | +1.457
Cl(r) | -0.2258 | -0.2126 | +0.01320 | +5.848

- NOTES
  - どちらも1000回の繰り返し計算の結果

6,049,050 nodes
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

7,278,072 nodes
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

y-yosuke, 2016-07-21:
検証のため 9M nodes ぐらいのメッシュが欲しいのだが 16.6M nodes が出来た... orz

y-yosuke, 2016-07-21:
9.4M nodes
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

y-yosuke, 2016-07-21:
（編集中）

fp-023b Test-C / Simlation 1 2 2 2 2 - 9.4M mesh / Run 1 / N=1000
```
sum of forces:
pressure : (189.774551594 -204.506482698 -58.9327120047)
viscous : (17.0136221008 -1.18795618197 0.760867178904)
porous : (0 0 0)
sum of moments:
pressure : (76.3681516223 123.156204543 74.4055919812)
viscous : (-0.082408700122 9.0932366984 11.0652133298)
porous : (0 0 0)
forceCoeffs forceCoeffs01 output:
Cm = 0.132977210555
Cd = 0.551004244533
Cl = -0.155003706637
Cl(f) = 0.0554753572367
Cl(r) = -0.210479063874
```

y-yosuke, 2016-07-22:
Node 数 7.3M と 8.2M と 9.4M の Coefficient の計算結果の比較

Coef. | 7,278,072 nodes | Difference +0.94M (+13.0%) | 8,222,209 nodes | Difference +1.19M (+14.5%) | 9,416,593 nodes
---|---|---|---|---|---
Cm |  0.1355 | 0.001151 (-0.849%) | 0.1344 | -0.001400 (-1.04%) | 0.1330
Cd |  0.5555 | -0.003114 (-0.561%) | 0.5524 | -0.001399 (-0.253%) | 0.5510
Cl |  -0.1540 | -0.006284 (-4.08%) | -0.1603 | +0.005329 (+3.32%) | -0.1550
Cl(f) |  0.05850 | -0.004293 (-7.34%) | 0.05421 | +0.001264 (+2.33%) | 0.05548
Cl(r) |  -0.2126 | -0.001991 (-0.937%) | -0.2145 | +0.004065 (+1.89%) | -0.2105
Core minutes (Runtime) | 3969 (125) |  +609 (+15.3%) | 4758 (149) | +943 (+19.8%) | 5701 (179)

- NOTES
  - いずれも 32 cores / 1000回の繰り返し計算の結果

-----

- 結果まとめ
  - 8.2M と 9.4M の違いで全ての Coefficient の変化率が 5% を下回った．
- 考察
  - 前回のメッシュの変化割合的な考察は 8.2M → 9.4M でも当てはまる予想ではあったが，計算結果からするとそれは当てはまらない．
  - Cl(f) の変化率が比較的大きく出るのは数値そのものが小さいことも考慮する必要がありそうだ．
    - 今後，フロントダウンフォースを増やした時にもう一度 Node 数と計算結果の関係を確認する必要がありそうだ．
  - 10%程度の Cefficient の変化を見るにも最低 9M は必要なように考える．
  - 9.4M Nodes のメッシュをコントロールとしてフロントのデバイスを変化させた場合の反応を見てゆく予定とする．
    - （8.2M Nodes ぐらいで安定してくれたらなぁ... と思っていたけどしょうがない）

-----

fp-023b Test-C / 8.2M nodes mesh / N=1000

```
forces forces00 output:
sum of forces:
pressure : (190.421098796 -203.724110884 -60.8971742144)
viscous : (16.8920990283 -1.17695569642 0.725367731956)
porous : (0 0 0)
sum of moments:
pressure : (76.8698680842 124.558126928 73.5427894986)
viscous : (-0.0547112785919 9.08387851351 10.9694922112)
porous : (0 0 0)
forceCoeffs forceCoeffs01 output:
Cm = 0.134377438043
Cd = 0.552403214885
Cl = -0.160332770393
Cl(f) = 0.0542110528462
Cl(r) = -0.21454382324
```

y-yosuke, 2016-07-22:
9.4M の STL Geometry, Mesh, Simulation を各1つずつ残したものとして下記URLに Control ケースとして作った．ここからコピー（ブランチ）すれば良い．
https://www.simscale.com/projects/yosukegb4/fp-023b_test-c_1/

（Control としてアカウント本人の編集もプロテクトできたら良いのにな）

y-yosuke, 2016-07-22:
今のモデルは車高を公道を走る前提で Front 110mm / Rear 110mm で行っている．

サーキットを走るような車高で計算する場合は更にアンダーパネルと地面の間のメッシュを細かくする必要がある．
（ただ，その場合はフェンダーとの干渉が出てくるのでボディパネルの位置も変更が必要となる）

y-yosuke, 2016-07-22:
メッシュの設定1段階間違ってて切り直そうとしたらエラーが出た．メモリーエラーと言われたけど違うこともあるし... 原因はなんだ？
- 前回のメッシュを切った結果を Delete result しないとエラーが出ることがある（消したつもりだけどなぁ...）
- fb-023b - Control の解析結果をダウンロードしながら Start させたのが悪かったか？

y-yosuke, 2016-07-26:
メッシュを切るときにエラーがでる場合の原因の1つ？ たまたま？
- 左右の wheel を1つの face set にするとメッシュ切り時にエラーになっている．たまたま？
  - NG? : fr-wheels , rr-wheels
  - Fine? : fl-wheel , fr-wheel , rl-wheel , rr-wheel

y-yosuke, 2016-07-27:
SimScale の Project のページの Comment (Edit on forum) で Post-process のスクリーンショットを載せるとファイル名もそのまま表示される．日本語で「スクリーンショット（＋日時分秒）」で表示される．

GitHub は関係ない名前に変えられるのと同じ感覚でアップロードしてしまったけど，
次はファイル名も気にしよう．

y-yosuke, 2016-08-19:
メッシュ切りのときに領域の内外の判定が原因と思われるエラー（表記上は全てメモリーエラーで出てくるけど）が出ることがある．おそらく次のような場合は駄目．

- 面で接している2つの領域で一方の外側がも一方の内側になっている場合
  - 面で接していても一方の外側がもう一方においても外側の場合はOK
    - ブーリアンをとってくれたら解決しそうな気もするけど...
- モデルと Mesh Refinements の Geometry Primitives の交差が細かいところにある，もしくは浅い角度で交差する場合
  - ちょっと確信がないですけど...

y-yosuke, 2016-08-20:
10M Nodes のメッシュで STL データアップロードから800回の繰り返し計算のシミュレーション終了まで各セッティング時間も含めて大体5時間ぐらい．

1. STLデータのアップロード＆ 1/1000スケーリング 0.5h
2. メッシュ切り 1h
3. シミュレーション計算 3h

y-yosuke, 2016-08-20:
2004〜5年ぐらいだとメッシュの数は忘れたけど車1台まるっぽで大体シミュレーション計算だけでワークステーション3台使ってだったか？3日ぐらいかかってたような気がする．記憶がかなり曖昧だけど．

それに比べたら速いし，サーバ側でやってくれて自分側のリソースは削られないし，Free だし，便利になったもんだ．

Closed 2017-06-29.

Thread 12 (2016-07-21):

More Fr Downforce!!

y-yosuke, 2016-07-21:
CFDの結果を信じる限りにおいてはフロントのダウンフォースが足りないらしい．
https://github.com/y-yosuke/formula-ppoino/issues/11#issuecomment-233866299

なのでフロントダウンフォースの増加策を考える．
https://github.com/y-yosuke/formula-ppoino/issues/11#issuecomment-233886791
の続き．

- [ ] ~~Monocoque ドライバ足下の面を水平に~~ → 座席法規 400mm x 400mm の確保が難しい
  - サスペンションジオメトリ，ペダル類の設計にもメリット有り
- [ ] Fr Wing Profile を厚くダウンフォースをより大きく発生しそうなものに
- [ ] Fr Wing - Fender の縦のつながりの部位外側にダクト
- [ ] Nose Cone S-Duct
- [ ] Side Deflector

CFD 解析をして大雑把な傾向を見ながら開発を進める．

とりあえず S-Duct ほい．
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

y-yosuke, 2016-07-22:
コピーで新しい Project を作成しているためか URL が1つずつずれる... (T_T) 間違いではない．

fp-023b - Front Aero Devices / SimScale
https://www.simscale.com/projects/yosukegb4/fp-023b_control/

fp-023b - Control / SimScale
https://www.simscale.com/projects/yosukegb4/fp-023b_test-c_1/

この Control から（当面は？）派生して部品の効きを見る．
効果が制度の問題で分らなかったらもっと細かいメッシュで効きを見る．

y-yosuke, 2016-07-22:
S-duct mesh
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

y-yosuke, 2016-07-22:
しまった，先に No Fr Flap をやって反応性を見るべきだった．

y-yosuke, 2016-07-22:
S-Duct - Control Comparison

Coef. | Control | S-Duct | Difference (%) | Remarks
---|---|---|---|---
Cm | 0.1330 | 0.12281 | -0.01022 (-7.69%) |
Cd | 0.5510 | 0.5488 | -0.002157 (-0.391%) |
Cl | -0.1550 | -0.1579 | -0.002855 (-1.84%) |
Clf | 0.05548 | 0.04382 | -0.01165 (-21.0%) | Lift の減少
Clr | -0.2105 | -0.2017 | +0.008797 (+4.18%) |
L/D | -0.2813 | -0.2876 | -0.006307 (-2.24%) |

S-Duct / fp-023 - Front Aero Devices
```
forces forces00 output:
sum of forces:
pressure : (189.010245301 -208.653664878 -60.1343191761)
viscous : (16.9684320088 -1.16034174011 0.89117434658)
porous : (0 0 0)
sum of moments:
pressure : (78.8520329094 112.828251548 80.4311111952)
viscous : (-0.103188723743 9.25318915636 11.0062719944)
porous : (0 0 0)
forceCoeffs forceCoeffs01 output:
Cm = 0.122753255461
Cd = 0.548847274259
Cl = -0.157858274375
Cl(f) = 0.0438241182741
Cl(r) = -0.201682392649
```

Control
```
forces forces00 output:
sum of forces:
pressure : (189.774551594 -204.506482698 -58.9327120047)
viscous : (17.0136221008 -1.18795618197 0.760867178904)
porous : (0 0 0)
sum of moments:
pressure : (76.3681516223 123.156204543 74.4055919812)
viscous : (-0.082408700122 9.0932366984 11.0652133298)
porous : (0 0 0)
forceCoeffs forceCoeffs01 output:
Cm = 0.132977210555
Cd = 0.551004244533
Cl = -0.155003706637
Cl(f) = 0.0554753572367
Cl(r) = -0.210479063874
```

y-yosuke, 2016-07-23:
S-Duct Post Process
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

y-yosuke, 2016-07-23:
Forward Deflector はよく分からない（かった）から次のデバイスは Wheel Inner Cover (Brake Duct) かな．Brake Duct の Outlet が今のところ無いから Cover 的なものだけにする予定だけど．

y-yosuke, 2016-07-23:
その前に Wing Profile の変更が先か？ でも Wing Profile の選び方がいまいち分らんし...

y-yosuke, 2016-07-23:
or... No Head Light ???

y-yosuke, 2016-07-23:
ヘッドライト無しが先だな．というかフロントフラップ無しよりも先ではないか？

y-yosuke, 2016-07-24:
（編集中）

No Head Light
```
forces forces00 output:
sum of forces:
pressure : (185.963987596 -202.29177286 -54.4615004491)
viscous : (17.080265145 -1.18840183838 0.710379161749)
porous : (0 0 0)
sum of moments:
pressure : (73.5338117467 126.131821048 69.9512263763)
viscous : (-0.0547257934216 9.02500352631 11.11020739)
porous : (0 0 0)
forceCoeffs forceCoeffs01 output:
Cm = 0.135900593232
Cd = 0.541028256545
Cl = -0.143224322013
Cl(f) = 0.0642884322255
Cl(r) = -0.207512754239
```

Control
```
forces forces00 output:
sum of forces:
pressure : (189.774551594 -204.506482698 -58.9327120047)
viscous : (17.0136221008 -1.18795618197 0.760867178904)
porous : (0 0 0)
sum of moments:
pressure : (76.3681516223 123.156204543 74.4055919812)
viscous : (-0.082408700122 9.0932366984 11.0652133298)
porous : (0 0 0)
forceCoeffs forceCoeffs01 output:
Cm = 0.132977210555
Cd = 0.551004244533
Cl = -0.155003706637
Cl(f) = 0.0554753572367
Cl(r) = -0.210479063874
```

y-yosuke, 2016-07-24:
Wing Profile はとりあえず Thickness を 40mm から 50mm に厚くしたものを計算するか．
今の Profile はデザイン的に良さそうな NACA の何番か（忘れた）を曲率的にスムースになるようにした適当なものなのだが．

y-yosuke, 2016-07-24:
No Head Light - Control GIF Animation Comparison
GIFアニメだと色調が荒くなってしまうなぁ...
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

y-yosuke, 2016-07-24:
No Head Light - Control / Pressure Comparison - PNG Pictures
GIFにする前のPNGファイルも貼っておく．
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

y-yosuke, 2016-07-24:
（編集中）

---

No Fr-Flap
```
forces forces00 output:
sum of forces:
pressure : (183.118993864 -188.385724772 -12.119203565)
viscous : (17.1214202757 -1.30651834498 0.683518707209)
porous : (0 0 0)
sum of moments:
pressure : (51.1007383281 230.240971324 48.3374569111)
viscous : (0.0440038353818 9.06392678954 11.1839704244)
porous : (0 0 0)
forceCoeffs forceCoeffs01 output:
Cm = 0.240621794123
Cd = 0.53355719598
Cl = -0.0304713310399
Cl(f) = 0.225386128603
Cl(r) = -0.255857459643
```

---

Control

```
forces forces00 output:
sum of forces:
pressure : (189.774551594 -204.506482698 -58.9327120047)
viscous : (17.0136221008 -1.18795618197 0.760867178904)
porous : (0 0 0)
sum of moments:
pressure : (76.3681516223 123.156204543 74.4055919812)
viscous : (-0.082408700122 9.0932366984 11.0652133298)
porous : (0 0 0)
forceCoeffs forceCoeffs01 output:
Cm = 0.132977210555
Cd = 0.551004244533
Cl = -0.155003706637
Cl(f) = 0.0554753572367
Cl(r) = -0.210479063874
```

y-yosuke, 2016-07-25:
Front Wing Profile Thickness 40mm → 50mm

Coef.	|	Control	|	Fr Wing t50	|	Difference	|	DIfference %	|	Remarks
---	|	---	|	---	|	---	|	---	|	---
Cd	|	0.5510	|	0.5504	|	-0.0006230	|	-0.113	|
Cl	|	-0.1550	|	-0.1521	|	+0.002928	|	+1.89	|
Clf	|	0.05548	|	0.04254	|	-0.01294	|	-23.3	|	Fr Lift の減少
Clr	|	-0.2105	|	-0.1946	|	+0.01587	|	+7.54	|	Rr Downforce の減少
L/D	|	-0.2813	|	-0.2763	|	+0.005002	|	+1.78	|

---

Fr Wing t50
```
forces forces00 output:
sum of forces:
pressure : (189.57605045 -204.860328573 -57.8362984627)
viscous : (16.9783139745 -1.18385305872 0.763498594613)
porous : (0 0 0)
sum of moments:
pressure : (76.1897487907 108.875470887 75.9412660267)
viscous : (-0.085452299519 9.05053303944 11.0346626722)
porous : (0 0 0)
forceCoeffs forceCoeffs01 output:
Cm = 0.118574951295
Cd = 0.550381240335
Cl = -0.152075210167
Cl(f) = 0.0425373462117
Cl(r) = -0.194612556379
```

y-yosuke, 2016-07-26:
Front Wing Profile Thickness 40mm → 50mm / Control - Pressure Comparison Picture
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

y-yosuke, 2016-07-26:
Fr Flap Angle +15 deg / Control - Coefficients Comparison

Coef.	|	Control	|	Fr Flap +15deg	|	Difference	|	DIfference %	|	Remarks
---	|	---	|	---	|	---	|	---	|	---
Cd	|	0.5510	|	0.5676	|	0.01663	|	+3.02	|
Cl	|	-0.1550	|	-0.1625	|	-0.007519	|	-4.85	|	Downforce の増加
Clf	|	0.05548	|	0.01918	|	-0.03630	|	-65.4	|	Fr Lift の減少
Clr	|	-0.2105	|	-0.1817	|	+0.02878	|	+13.7	|	Rr Downforce の減少
L/D	|	-0.2813	|	-0.2863	|	-0.005006	|	1.78	|

---

Fr Flap Angle +15 deg
```
forces forces00 output:
sum of forces:
pressure : (196.141029969 -204.623799124 -61.7673440098)
viscous : (16.8867651451 -1.15449314662 0.773799086001)
porous : (0 0 0)
sum of moments:
pressure : (77.4477771541 90.8383305757 85.8146981629)
viscous : (-0.107658524065 9.05275146911 10.9530665667)
porous : (0 0 0)
forceCoeffs forceCoeffs01 output:
Cm = 0.100440783151
Cd = 0.567630233463
Cl = -0.162522360644
Cl(f) = 0.0191796028293
Cl(r) = -0.181701963473
```

y-yosuke, 2016-07-27:
Front Fender Narrow Pillar / Front Wing t50 - Comparison of Coefficients

Coef.	|	Fr Wing t50	|	Fr Fender Nrw Pillar	|	Difference	|	DIfference %	|	Remarks
---	|	---	|	---	|	---	|	---	|	---
Cm	|	0.1186	|	0.1478	|	0.02921	|	24.6	|
Cd	|	0.5504	|	0.5462	|	-0.004190	|	-0.761	|
Cl	|	-0.1521	|	-0.1256	|	0.02644	|	-17.4	|	Decrease of Downforce
Clf	|	0.04254	|	0.08497	|	0.04243	|	99.7	|	Increase of Front Lift
Clr	|	-0.1946	|	-0.2106	|	-0.01598	|	8.21	|	Increase of Rear Downforce
L/D	|	-0.2763	|	-0.2300	|	0.046297	|	-16.76	|

- 計算回数 N=900 の値
  - Core hours が 3000 に近づいたためか計算時間を長めに設定していたら最初からエラーが出たため計算時間を短めにしていたら N=960 で計算終了になったため．

---

- Front Downforce を増加させたい方向とは真逆の結果
  - Front Lift がほぼ倍の大きさに... orz
  - そうであるのならこの形状変化の真逆を行えば Front Downforce を増やすことができる？

---

- Solver Log には 500行 分の Log しか表示されないので force outut, coefficient output はたまたま表示範囲外であった．
  - force result, coefficient result の結果は繰り返し計算の100回に1回しか計算していないため．
  - Web の Post-process の Force coefficients plot の表示から結果をコピペした．

y-yosuke, 2016-08-02:
Front Wheel Deflector - t10 / R5
まずは板状の単純なもので様子を見る．良さそうだったら隅に Fillet をかけたものなどを試す．
この Wheel Deflector のために Wheel House (Inner Fender) の面も新規のもの．
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

y-yosuke, 2016-08-02:
Front Wheel Deflector - t10 / R5
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
y-yosuke, 2016-08-09:
Front Fender Louver / fp-023c Control - Coefficient Comparison

---

Body and Wheels		
		
Coef.	|	fp-023c Control	|	Fr Fender Louver	|	Difference	|	DIfference %	|	Remarks
---	|	---	|	---	|	---	|	---	|	---
Cm	|	0.0781	|	0.0696	|	-0.0085	|	-10.8	|
Cd	|	0.5590	|	0.5619	|	+0.0029	|	+0.5	|
Cl	|	-0.1693	|	-0.1805	|	-0.0112	|	-6.6	|
Clf	|	-0.0066	|	-0.0206	|	**-0.0141**	|	-214.7	|
Clr	|	-0.1627	|	-0.1599	|	+0.0028	|	+1.8	|
CoP	|	0.9613	|	0.8858	|	-0.0755	|	**-7.6**	|
L/D	|	-0.3028	|	-0.3212	|	-0.0184	|	**-6.1**	|

---

Body Only		
		
Coef.	|	fp-023c Control	|	Fr Fender Louver	|	Difference	|	DIfference %	|	Remarks
---	|	---	|	---	|	---	|	---	|	---
Cm	|	0.0610	|	0.0512	|	-0.0097	|	-12.5	|
Cd	|	0.4385	|	0.4430	|	+0.0045	|	+0.8	|
Cl	|	-0.2099	|	-0.2242	|	-0.0143	|	-8.4	|
Clf	|	-0.0440	|	-0.0609	|	-0.0169	|	-257.6	|
Clr	|	-0.1659	|	-0.1633	|	+0.0026	|	+1.6	|
CoP	|	0.7904	|	0.7285	|	-0.0619	|	-6.2	|
L/D	|	-0.4787	|	-0.5060	|	-0.0273	|	-9.0	|

---

Front Fender Louver (N=800)

```
forces forces00 output:
sum of forces:
pressure : (194.021035364 -214.194593019 -68.69904829)
viscous : (16.8682687652 -1.13925669691 0.970496265636)
porous : (0 0 0)
sum of moments:
pressure : (86.4583824343 59.9632167236 89.7150662382)
viscous : (-0.162704736168 9.27297690372 11.0187434161)
porous : (0 0 0)
forceCoeffs forceCoeffs02 output:
Cm = 0.0512147526915
Cd = 0.442997031299
Cl = -0.224164879662
Cl(f) = -0.0608676871393
Cl(r) = -0.163297192522
forceCoeffs forceCoeffs01 output:
Cm = 0.069617200735
Cd = 0.561932046816
Cl = -0.180468345818
Cl(f) = -0.0206169721743
Cl(r) = -0.159851373644
```

---

Front Fender Louver / Screen Shot Images
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

y-yosuke, 2016-08-10:
Front Fender Louver - Stream
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

y-yosuke, 2016-08-10:
Front Fender Louver / fp-023c Control - Pressure Comparison
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

y-yosuke, 2016-08-10:
Front Fender Louver / fp-023c Control - U Magnitude Comparison
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

y-yosuke, 2016-08-10:
Front Fender Louver **B** / fp-023c Control - Coefficient Comparison

---

Body and Wheels		
		
Coef.	|	fp-023c Control	|	Fr Fender Louver B	|	Difference	|	DIfference %	|	Remarks
---	|	---	|	---	|	---	|	---	|	---
Cm	|	0.0781	|	0.0611	|	-0.0169	|	-21.7	|
Cd	|	0.5590	|	0.5636	|	**+0.0046**	|	+0.8	|
Cl	|	-0.1693	|	-0.1930	|	-0.0237	|	-14.0	|
Clf	|	-0.0066	|	-0.0354	|	**-0.0288**	|	-439.7	|
Clr	|	-0.1627	|	-0.1576	|	+0.0051	|	+3.1	|
CoP	|	0.9613	|	0.8168	|	-0.1445	|	**-14.4**	|
L/D	|	-0.3028	|	-0.3424	|	**-0.0397**	|	-13.1	|

---

Body Only		
		
Coef.	|	fp-023c Control	|	Fr Fender Louver B	|	Difference	|	DIfference %	|	Remarks
---	|	---	|	---	|	---	|	---	|	---
Cm	|	0.0610	|	0.0417	|	-0.0193	|	-24.7	|
Cd	|	0.4385	|	0.4445	|	+0.0061	|	+1.1	|
Cl	|	-0.2099	|	-0.2416	|	-0.0317	|	-18.7	|
Clf	|	-0.0440	|	-0.0791	|	-0.0351	|	-535.9	|
Clr	|	-0.1659	|	-0.1625	|	+0.0034	|	+2.1	|
CoP	|	0.7904	|	0.6726	|	-0.1179	|	-11.8	|
L/D	|	-0.4787	|	-0.5434	|	-0.0647	|	-21.4	|

---

Front Fender Louver **B** (N=800)

```
forces forces00 output:
sum of forces:
pressure : (194.532736763 -215.087078872 -73.4640487952)
viscous : (16.9690734028 -1.110422533 1.03726612724)
porous : (0 0 0)
sum of moments:
pressure : (89.5275518637 51.3640488125 90.3860205617)
viscous : (-0.239180640785 9.44157798426 11.1084927904)
porous : (0 0 0)
forceCoeffs forceCoeffs02 output:
Cm = 0.0416830547389
Cd = 0.444519459948
Cl = -0.241557483711
Cl(f) = -0.0790956871165
Cl(r) = -0.162461796594
forceCoeffs forceCoeffs01 output:
Cm = 0.0611402404545
Cd = 0.563564119966
Cl = -0.192987171147
Cl(f) = -0.0353533451189
Cl(r) = -0.157633826028
```

y-yosuke, 2016-08-11:
Front Fender Louver - Stream
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

y-yosuke, 2016-08-11:
Front Fender Louver **B** / Front Fender Louver - U Magnitude Comparison
Slice Y=-800mm
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

y-yosuke, 2016-08-11:
Side
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

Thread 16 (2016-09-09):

シミュレーションの内容を英語で説明

y-yosuke, 2016-09-09:
して欲しいです，とのことで英語編集用の Issue．ここで編集してHTMLでコピーかな．
英語でメールよりも長い文章書くの久しぶり... orz （そんなに長くないけど）

今週末（〜2016年9月11日）に書き上げる予定．

説明の対象は主に fp-023c - Front Aero Devices
https://www.simscale.com/projects/yosukegb4/fp-023c_-_control/

fp-023b - Front Aero Devices も関係してくるんだけどどの程度絡めるか？
https://www.simscale.com/projects/yosukegb4/fp-023b_control/

酷い英語があったら指摘して頂けるとありがたいです．

y-yosuke, 2016-09-09:
Editing now...

The Car

This car project is my formula style 2-seater car project published in GitHub.

https://github.com/y-yosuke/formula-ppoino
https://github.com/y-yosuke/ppoino-cars

"fp" are the initials of "formula-ppoino". "-ppoino" is a Japanese expression that means "a thing(s) looks/sounds like -", so "formula-ppoino" means "a car looks like formula".

I designed the car in the style of the early 2000s formula cars.
The reason of "2-seater" is to feel the joy riding in the formula car with friends on the road, it is not only for the competitions in racing circuits.

The model

I designed the car using Rhinoceros.

For importing multiple faces body, front wheels and rear wheels into one geometry, I export ASCII STL files of the each faces from Rhinoceros and edit the names of the solids in these ASCII STL files manually. Then I put these STL files together into the one STL file using "cat" command and upload it.

The size of the mesh is required 9M nodes at least in this case. It was derived from the result of the simulations in "fp-023b Test-C".
https://www.simscale.com/projects/yosukegb4/fp-023b_test-c/

The aim of the simulations

front and rear downforce balance

y-yosuke, 2016-09-09:
Editing now...

## The aim of the simulations

Generally in the aerodynamic development of the racing cars, you mainly focus on the characteristics below.

- Downforce, Drag, L/D
- Balance of the front and rear downforces
- Sensitivity of the Downforce and Balance to the vehicle ride heights

Through the simulations of ""fp-023b Test-C" https://www.simscale.com/projects/yosukegb4/fp-023b_test-c/", I found the front downforce was not enough. It depends on the car weight balance and how the vehicle ride heights change, but I provisionaly set the goal that the center of the front and rear downforces will be about 60-65%. ( Clf : Clr = 40-35 : 60-65 )

emijah, 2016-09-09:
Edited

## The aim of the simulations

Generally, during aerodynamic development of racing cars, you mainly focus on the characteristics below.

- Downforce, Drag, L/D
- Balance of the front and rear downforces
- Sensitivity of the Downforce and Balance to the vehicle ride heights

Through simulation, as in ""fp-023b Test-C" https://www.simscale.com/projects/yosukegb4/fp-023b_test-c/", I found there was insufficient front downforce. It depends on the car weight balance and how the vehicle ride heights change, but I provisionaly set the goal to distribute the front and rear downforces to be about 60-65%. ( Clf : Clr = 40-35 : 60-65 )

y-yosuke, 2016-09-09:
@emijah ありがとうございます！

y-yosuke, 2016-09-09:
Editing...

Through simulations, as in "fp-023b - Front Aero Devices https://www.simscale.com/projects/yosukegb4/fp-023b_control/ ",

emijah, 2016-09-09:
@y-yosuke これよりも前の部分は直接投稿した文書を編集してしまったかもしれません。確認しますね。

emijah, 2016-09-09:
Edited

## The car

This car project is my formula style 2-seater car project published in GitHub.

https://github.com/y-yosuke/formula-ppoino

I designed the car in the style of the early 2000s formula cars. The reason it's a "2-seater" is to allow you to share the joy of riding in a formula car with your friends on the road, it is not only for competition on racing circuits.

The prefix "fp" are the initials of "formula-ppoino". "-ppoino" is a Japanese expression that means "thing(s) looks/sounds/drives like -", so "formula-ppoino" means it "looks like a formula car".

## The model

I designed the car using the modelling software Rhinoceros.

To import multiple faces, the body, front wheels and rear wheels into one geometry, I exported ASCII STL files of each faces from Rhinoceros and edited the names of the solids in these ASCII STL files manually. Then I put these STL files together into the one STL file using "cat" command and uploaded it.

The size of the mesh required is at least 9M nodes in this case. It was derived from the result of the simulations in "fp-023b Test-C".
https://www.simscale.com/projects/yosukegb4/fp-023b_test-c/

y-yosuke, 2016-09-09:
ちなみに SimScale の中の人から説明を書き加えて下さいというお願いで，
下記フォーラムのページを参考にここまでは全然詳しくなくて大丈夫とのこと．
https://www.simscale.com/forum/t/wind-turbine-blade-fluid-and-structural-optimisation-using-cae/37492

主に私が SimScale に貼った ParaView で Post-process した画像の解説が欲しいそうです．
（それらの説明がそれなりであれば）Project Spotlight として来週あたり紹介するかもとのこと．

emijah, 2016-09-09:
よかったねぇ！
実際につくラメのスポンサーも募集中と書いてみては？

2016年9月9日 19:02 Yosuke Yamamoto <notifications@github.com>:

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

y-yosuke, 2016-09-09:
GitHub のコメントって編集履歴は残らないんでしたっけ？

y-yosuke, 2016-09-09:
## The result of "fp-023b - Front Aero Devices" (Summary)

- S-Duct
- Front Wing t40/t50 Comparison
- Front Fender Narrow Pillar
- Front Inner Fender Modification
- Front Flap
  - Position X+20mm
  - Angle +7.5deg (mechanical MAX +15deg)

## The result of "fp-023c - Front Aero Devices"

y-yosuke, 2016-09-10:
Editing...

## fp-023c - Front Aero Devices

y-yosuke, 2016-09-10:
【 fp-023c - Summary of the Results (Part 2) 】Front Fender Stay (Part 1)

Edited in https://github.com/y-yosuke/formula-ppoino/issues/12#issuecomment-246096612

y-yosuke, 2016-09-10:
【 fp-023c - Summary of the Results (Part 3) 】Front Fender Stay (Part 2)

Edited in https://github.com/y-yosuke/formula-ppoino/issues/12#issuecomment-246107120

y-yosuke, 2016-09-10:
後は...

- [ ] S-Duct B の比較
- [ ] Ride height の比較

かな．
渦度に関しては私の工学的な理解が浅いので説明はしないでおこうかと思っている．

y-yosuke, 2016-09-11:
【 fp-023c - Summary of the Results (Part 4) 】S-Duct B

Edited in https://github.com/y-yosuke/formula-ppoino/issues/12#issuecomment-246163741

y-yosuke, 2016-09-11:
Front / Rear のダウンフォースの割合は風洞実験の経験から設定した暫定値なので
本シミュレーション上ではそれは Body Only の Coefficients に相当するから "of the body" を入れた方が良い気がする．

> I provisionaly set the goal to distribute the front and rear downforces to be about 60-65%.

I provisionaly set the goal to distribute the front and rear downforces of the body to be about 60-65%.

y-yosuke, 2016-09-11:
"
Ride Heights Comparison

Ideally, various vehicle ride heights are tested for each aero-devices to know the sensitivity of the downforce and balance to the ride heights. But it needs a lot of 'core hours' to solve.
"

y-yosuke, 2016-09-11:
【 fp-023c - Summary of the Results (Part 5) 】Front Fender Louver C + Louver Stay B

Edited in https://github.com/y-yosuke/formula-ppoino/issues/12#issuecomment-246167618

y-yosuke, 2016-09-11:
【 fp-023c - Summary of the Results (Part 6) 】Ride Heights Comparison

Edited in https://github.com/y-yosuke/formula-ppoino/issues/12#issuecomment-246168325

y-yosuke, 2016-09-11:
私の知識で説明出来るのは大体これら ↑ ぐらいかな．

やはり乱流エネルギー k の図は説明に十分な知識を持ち合わせていないので避けておこう．

y-yosuke, 2016-09-12:
修正していただいたものをまとめ，あんど，投稿．

## The car

This car project is my formula style 2-seater car project published in GitHub.

https://github.com/y-yosuke/formula-ppoino

I designed the car in the style of the early 2000s formula cars. The reason it's a "2-seater" is to allow you to share the joy of riding in a formula car with your friends on the road, it is not only for competition on racing circuits.

The prefix "fp" are the initials of "formula-ppoino". "-ppoino" is a Japanese expression that means "thing(s) looks/sounds/drives like -", so "formula-ppoino" means it "looks like a formula car".

## The model

I designed the car using the modelling software Rhinoceros.

To import multiple faces, the body, front wheels and rear wheels into one geometry, I exported ASCII STL files of each faces from Rhinoceros and edited the names of the solids in these ASCII STL files manually. Then I put these STL files together into the one STL file using "cat" command and uploaded it.

The size of the mesh required is at least 9M nodes in this case. It was derived from the result of the simulations in "fp-023b Test-C".
https://www.simscale.com/projects/yosukegb4/fp-023b_test-c/
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
emijah, 2016-09-12:
そうそう。キーワードをlouvre aerodynamicにしないと永久にリファレンスは出てきません

2016-09-12 12:33 GMT+09:00 Yosuke Yamamoto <notifications@github.com>:

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

y-yosuke, 2016-09-12:
シミュレーションの結果のまとめ各項目もこっちにコピーしておいた方が良かったですか？

Front Fender Louvers
Content here : #12 (comment)

y-yosuke, 2016-09-12:
前半の修正点 ^ 理解・了解しました．

emijah, 2016-09-12:
Edited

## Front Fender Louvres

Content here : https://github.com/y-yosuke/formula-ppoino/issues/12#issuecomment-246084217

## Front Fender Stay (Part 1)

Content here : https://github.com/y-yosuke/formula-ppoino/issues/12#issuecomment-246096612

## Front Fender Stay (Part 2)

Content here : https://github.com/y-yosuke/formula-ppoino/issues/12#issuecomment-246107120

## S-Duct B

Content here : https://github.com/y-yosuke/formula-ppoino/issues/12#issuecomment-246163741

## Front Fender Louvre C + Louvre Stay B

Content here : https://github.com/y-yosuke/formula-ppoino/issues/12#issuecomment-246167618

## Ride Heights Comparison

Content here : https://github.com/y-yosuke/formula-ppoino/issues/12#issuecomment-246168325

## Conclusions

Conclusions or Conclusion ???

Content here : https://github.com/y-yosuke/formula-ppoino/issues/12#issuecomment-246227805

emijah, 2016-09-12:
動画とか見入っちゃいますね

y-yosuke, 2016-09-12:
これはリンク先の英語の内容も大丈夫だったということでしょうか？

y-yosuke, 2016-09-12:
SimScale の forum は基本的には Markdown に対応しているものの Markdown の表には対応していない HTML でないとだめのようだ．

emijah, 2016-09-12:
リンク先は後で確認します

y-yosuke, 2016-09-12:
すみません．よろしくお願い致します．

y-yosuke, 2016-09-12:
HTML でも’表’が表示されないなぁ...

y-yosuke, 2016-09-12:
表は TeX で書きなはれ，ということなのかな？
https://www.simscale.com/forum/t/mathjax-arrays/444

y-yosuke, 2016-09-12:
TeX でも表示されない．キャプチャして画像貼りつけかな．

y-yosuke, 2016-09-12:
Louver / Louvre 問題は既に ParaView キャプチャした画像に Louver で書いてあるので Louver で統一します．

y-yosuke, 2016-09-12:
もしかしてこれらのドキュメント全体の標題も必要な気がしてきた...
Result of "fp-023c Front Aero Devices" ? Results ???

emijah, 2016-09-12:
@y-yosuke なにー！(Louvre)

fp-023c - Front Aero Device Study

はどうですか？

y-yosuke, 2016-09-12:
@emijah すみません (Louvre)

標題はそれにしましょう．

y-yosuke, 2016-09-12:
アップロード始めました．"Sorry. Now Editing..." を冒頭に書きながら．
追加修正点は私が後から手動修正します．
https://www.simscale.com/forum/t/fp-023c-control-simulation-project-by-yosukegb4/36689/17

y-yosuke, 2016-09-13:
説明用にアップロードした画像をこちらにも保管しておく．
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

y-yosuke, 2016-09-13:
（図を多く貼るとボリュームが出て沢山書いたような気分になる）

y-yosuke, 2016-09-13:
全体の項目の階層を次のようにして投稿済みとしました．
@emijah さん，協力いただき大変ありがとうございました．

### Contents

- Introductions
  - Car
  - Model
  - Conditions
  - Aim of the simulation
  - Summary of simulation "fp-023b - Front Aero Devices"
- Simulations
  - Front Fender Louvers
  - Front Fender Stay (Part 1)
  - Front Fender Stay (Part 2)
  - S-Duct B
  - Front Fender Louver C + Louver Stay B
  - Ride Height Comparison
  - Conclusion

y-yosuke, 2016-09-13:
（あれもこれも説明しなきゃと思って of とか the とかいろいろと増殖して格好悪い表現になっていく私の英語力... orz）

y-yosuke, 2016-09-14:
無事に紹介されました．URLもそれらしいものに変えて頂いたようです．
https://www.simscale.com/forum/t/fp-023c-front-aero-device-study/36689

あらためて @emijah さん協力ありがとうございました．

ということで，この Issue は Close します．

y-yosuke, 2016-09-14:
（そういえば SimScale は OnShape や Autodesk と連携しているから Rhinoceros に関係した記述も編集されずにそのままだったな... ）

emijah, 2016-09-14:
連携ができているということはツールとしては大きなことですからね。中途半端な支援しかできずもうしわけないです。

y-yosuke, 2016-09-14:
いえいえ，修正して頂いた点から英語の感覚が少し分って良かったです．

OnShape / Autodesk はテクニカルパートナーなのかな？と勝手に思っていましたが
いらぬ心配だったようです．

Closed 2016-09-14.

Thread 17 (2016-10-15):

Rr Bodywork

y-yosuke, 2016-10-15:

y-yosuke, 2016-11-16:
In the case of "Side Mirror-less", are there enough spaces for side view monitors on a dashboard?

y-yosuke, 2017-07-13:
CFD of Rear Bodywork : See #31

y-yosuke, 2017-12-11:
Head Rest 〜 Rr Bonnet に掛けての 凸凸 をシュッとさせた．

- デザイン上の修正 / Fixing Design issues
- 絞込角度を緩くして低ドラッグ化しないか期待 / Expecting to reduce the drug by narrowing down the shape

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

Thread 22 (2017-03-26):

Round Shape Display on Steering Wheel

y-yosuke, 2017-03-26:
ステアリングホイール設置のディスプレイを
円形のディスプレイにしてステアリングホイールを回しても表示をその分逆回しにして
見かけ上回らないようにするものがないか？ できないか？

y-yosuke, 2017-03-26:
シャープ、円形液晶も実現可能な「フリーフォームディスプレイ」開発。IGZO応用。ウェアラブルにも
http://av.watch.impress.co.jp/docs/news/653959.html

シャープは今どうなっているのだろう？

y-yosuke, 2017-03-26:
出来るだろうけど，簡単に調達可能か？というところか．直径 120mm ぐらい．

y-yosuke, 2017-03-26:
四角のディスプレイでも丸枠をつけて，はみ出した部分は別窓ディスプレイとして利用すれば良いか．

y-yosuke, 2017-03-26:
下のスクショで内側の丸が直径 116mm なので使えそうな大きさ．
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

y-yosuke, 2017-03-27:
円と四角
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

emijah, 2017-03-28:
丸い方が形がいいですね。

2017-03-27 14:14 GMT+09:00 Yosuke Yamamoto <notifications@github.com>:

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

y-yosuke, 2017-03-28:
四角はF1のようなスパルタンな感じがしますね．
丸はカジュアルな感じで公道を楽しむクルマのコンセプトには合っているようにも思います．

丸の場合は表示はクラシカルなアナログメータ表示モードがあると良いかも．

emijah, 2017-03-29:
ってことは、用途により使い分けを促せるんですね。
四角いディスプレイの場合はレースモードになって、パワー重視セッティング。丸いディスプレイは峠で楽しむレベルの距離重視セッテイングになるというのもいいですね。

2017年3月29日 2:48 Yosuke Yamamoto <notifications@github.com>:

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

y-yosuke, 2017-03-30:
円形はそれに見合ったディスプレイがリーズナブルに調達可能な場合に採用というところでしょうか．

CANの仕様等私は分っていないのですが，CAN通信をする市販のステアリングホイールがあれば
ソフトウェアの調整等は必要としても，それと互換可能にすることはできるのかな？

y-yosuke, 2017-04-07:
速度とか加速度などはパッセンジャーと共有した方が楽しそうだし，
センターコンソールのディスプレイに表示した方が良いように思う．

y-yosuke, 2017-04-20:
https://github.com/y-yosuke/ppoino-cars/issues/8#issuecomment-295570767

emijah, 2017-04-20:
OBD通信が読めるのかどうかというところでしょうかね？

2017年3月30日 14:46 Yosuke Yamamoto <notifications@github.com>:

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

y-yosuke, 2021-03-22:
ホンダのコンセプトカー？ でステアリング中心に丸形のディスプレイを設けて，ステアリングホイールを回しても表示が回らないようにしている動画がありました．
https://youtu.be/DT47g-OvCGg?t=92

y-yosuke, 2021-04-14:
Koenigsegg Gemera はステアリングホイール軸上ではないけど液晶ディスプレイ表示を回転させて水平にしている．

The $2m Koenigsegg Gemera That I Chased AROUND THE WORLD!
https://youtu.be/Y3qgpbuw9f0?t=621

emijah, 2021-04-15:
> ステアリングホイール設置のディスプレイを
> 円形のディスプレイにしてステアリングホイールを回しても表示をその分逆回しにして
> 見かけ上回らないようにするものがないか？ できないか？

解像度にかなり余裕が必要そう。でも描いて確認することはできますね

y-yosuke, 2021-06-22:
ベントレー、ゲームと共用できるステアリングホイール開発…パイクスピーク2021参戦車に装着https://response.jp/article/img/2021/06/22/346975/1645636.html

y-yosuke, 2022-03-27:
Koenigsegg のステアリングメータパネルも水平保持式

- Ultimate Koenigsegg Factory Tour With Christian Von Koenigsegg
  - https://youtu.be/30TFrquvs9g?t=1125

y-yosuke, 2022-04-01:
- 1080P Round Shape LCD Video Display 5” (130mm) Diameter
  - https://www.youtube.com/watch?v=M7b6qAsA16k

emijah, 2022-04-02:
うーーーーん、いつまで作っているか、ですね。一般的に使われる用途があればいいのですが。
掛け時計か置き時計としてsmart clockが普及すると、心配せずに使えそうですね

2022年4月2日(土) 0:30 Yosuke Yamamoto ***@***.***>:

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

y-yosuke, 2022-04-02:
四角いディスプレイでも丸くフレームを作ってあとはステアリングホイール構造物のようなフリして隠してしまえばできそうですけどね．

y-yosuke, 2022-04-02:
こういう ↓ 需要が続けば継続的に丸形も生産されるかな．

- Cammus StreetSport 60mm i-Round LCD Gauge Multifunction
  - https://shop.windbooster.com/product/60mm-round-lcd-gauges/
  - https://cammus.com/streetsport-lcd-meter/

emijah, 2022-04-03:
Ikea, ニトリの時計が無敵だと思います。
一般車車の計器でも良いですね

2022年4月2日(土) 13:32 Yosuke Yamamoto ***@***.***>:

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

y-yosuke, 2022-05-27:
- Bentley GT3 Fanatec Steering Wheel
  - https://bentley.fanatec.com/

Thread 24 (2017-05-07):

Fr Suspension

y-yosuke, 2017-05-07:
#3

y-yosuke, 2017-05-07:
Fr camber angle about 10deg

- Bump Steer
  - Stroke Z+50mm : 0.0493 Toe Out
  - Stroke Z-50mm : 0.0202 Toe Out

y-yosuke, 2017-05-16:
第9回 chapter3 サスペンション・デザイン
その5:ステアリング・ジオメトリーとその検討
https://www.zf.com/japan/ja_jp/corporate/motorsports_1/webseminar/9chapter3/webseminarvol9chapter3.html
"少なくとも走行時に起点となるサスペンション・ストロークから縮み・伸びのストロークが始まる範囲では、トー変化が出ない設計としたい。さらにストロークが深くなったところでトー変化が生じざるをえない場合は、バンプ→トーアウト(タイロッド前方配置ならナックルアーム端が外側へ、後方配置なら逆に内側へ)にしたほうがドライビングの対応は多少楽になる。"

y-yosuke, 2017-05-16:
ステアリングラックをもう少し高い位置にしたら良いのかな？

emijah, 2017-05-16:
う、フロントサスのレイアウトが頭に入っていない..

2017-05-16 10:59 GMT+09:00 Yosuke Yamamoto <notifications@github.com>:

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

y-yosuke, 2017-05-16:
@emijah あ，「？」を気にしないで下さい．自分への問いが多いので．

y-yosuke, 2017-05-16:
ステアリングラックを 10mm 高くした場合

- Stroke Z+50mm : 0.46 deg Toe Out
- Stroke Z-50mm : 0.71 deg Toe In

桁違いに角度が大きくなる．
Toe In/Out 逆だけど元の位置の方が絶対的に角度が小さいし良いような気がする．

y-yosuke, 2017-05-16:
今のサスペンションレイアウト（線図）
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

y-yosuke, 2017-05-16:
分りにくいので四面図
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

y-yosuke, 2017-05-16:
部品を表示したキャプチャ
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

y-yosuke, 2017-05-17:
Parts Assembly
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

y-yosuke, 2017-05-17:
（機能的にという意味ではなくて値段的に高級サスペンションになってしまいそうな...）

y-yosuke, 2017-06-15:
Spherical / Rodend Angle

- Upr Wishbone Inner :
- Lwr Wishbone Inner : 9.1389 deg

y-yosuke, 2017-06-15:
Spherical MBW-15VCR for Front Lower Wishbone Inner Points

y-yosuke, 2017-06-15:
Rodend HR15E = angle 11 deg
+ Dia.18 mm Collars (or Dia. 19mm with Chamfer 0.5mm) -> angle 12.5 deg

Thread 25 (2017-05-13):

Steering System

y-yosuke, 2017-05-13:
Picture of Ariel Atom steering rack
https://en.wikipedia.org/wiki/Steering#/media/File:WrightspeedStearingRack4888.JPG

y-yosuke, 2017-05-13:
Steering shaft layout comparison (yellow lines for the each)

- Offset and angled pinion gear steering rack
  - 2 additional joints (2 symmetrical universal joints)
  - Constant velocity
  - 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

- T-type steering rack
  - 3 additional joints (1 pair of bevel gears and 2 asymmetrical universal joints)
  - NOT constant velocity
  - Can be rearranged left and right
  - 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

- Centered steering rack and offset bevel gear box
  - 2 additional joints (2 pairs of bevel gears)
  - Constant velocity
  - Can be rearranged left and right
  - 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

y-yosuke, 2017-10-14:
See Steering Shaft Layout - Audi LMP Body in Half
https://i.imgur.com/D1LpW.jpg

y-yosuke, 2022-01-17:
KYB、パワースポーツ車両向けEPSを米ポラリス社のオフロードビークルに展開
https://response.jp/article/2022/01/17/353240.html?utm_source=twitter&utm_medium=social

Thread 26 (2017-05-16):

Cockpit Console

y-yosuke, 2017-05-16:
Rear View Monitor Layout

8inch ResizingLCD 300nits LED BackLight / 1024×324　215×79.2×7.5
http://www.skr-tech.co.jp/okugailcdkanban.htm

Driver's perspective
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

y-yosuke, 2017-05-16:
RH/LH コンパチブルにするためにセンターに置きたいところだけど...
無理せずに助手席側にずらすか...

y-yosuke, 2017-05-17:
いや，バックビューモニターがそもそも不要か．

emijah, 2017-05-17:
不要に一票

2017-05-17 13:31 GMT+09:00 Yosuke Yamamoto <notifications@github.com>:

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

y-yosuke, 2017-05-17:
@emijah ですよね．

カーナビなどと同じで欲しければ勝手に付けて下さいで済みますね．
左ハンドル用のステアリングシャフトの締結点もモノコック側に余るだろうし Aux Power ぐらい出すし．

y-yosuke, 2017-05-17:
Ariel Atom Interior
https://www.autocar.co.uk/car-review/ariel/atom/interior

y-yosuke, 2017-10-11:
Cockpit Panel and Bulkhead
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

y-yosuke, 2017-10-12:
肩部の幅が 510mm ぐらいなので
バケットシートに座った状態の肩幅がそれを超える場合は痩せてください．

y-yosuke, 2017-10-13:
- Cockpit Interfeces
  - Cut Off
  - Fire
  - Hazard Lamp
  - Shift Switch
    - Drive
      - Insane
      - Normal
      - Eco / Long Drive
    - Neutral
    - Reverse
    - Park
  - Parking Brake (Electrical Switch?)
  - Turn
    - Left
    - Right
  - Head Light
    - High
    - Low
  - Horn
  - Braking Ratio
  - EV Brake Mode Selector

and anything else?

emijah, 2017-10-15:
InsaneはTeslaの匂いがちょっとしますね。もう少し違った表現がないですかね？

2017-10-14 0:26 GMT+09:00 Yosuke Yamamoto <notifications@github.com>:

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

y-yosuke, 2017-10-15:
Ridiculous Mode, Ludicrous Mode もテスラが使ってるっぽいですね．
日本語だったら「加速番長」

y-yosuke, 2017-10-15:
Dual Motor で Software Differencial だったらその調整インタフェースも欲しいか．
可能な限りインタフェースはメカニカルにしたい．

emijah, 2017-10-18:
「加速番長」いいですね。
「交差点GP」ボタンにするといろいろと問題が起きそうですね。

2017-10-15 21:30 GMT+09:00 Yosuke Yamamoto <notifications@github.com>:

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

y-yosuke, 2017-10-22:
絶対NG「煽りモード」

emijah, 2017-11-17:
人名が出てこなければ一般名詞だから...

2017-10-22 15:26 GMT+09:00 Yosuke Yamamoto <notifications@github.com>:

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

y-yosuke, 2017-12-11:
Cockpit Panels
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

y-yosuke, 2018-01-29:
サイドミラーの大きさは
自動車用もバイク用もいわゆる「新保安基準」適合であれば同じで良いと読めるけどあってるかな？
http://www.mlit.go.jp/common/000187515.pdf

emijah, 2018-01-29:
実際に相談するしかなさそうですね。でもミニみたいにデザインを優先して見にくいミラーもあるので、意外と自由なのかもしれないですね。

2018-01-29 17:26 GMT+09:00 Yosuke Yamamoto <notifications@github.com>:

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

y-yosuke, 2018-01-29:
BMWのミニは画像を検索している限りでは保安基準に適合してそうに見えます．

y-yosuke, 2018-01-29:
むしろ適合するギリギリのサイズに合わせると 直径78mm の円を含む 69cm^2 以上の面積から
左右を詰めたような変な大きさになります．

emijah, 2018-01-29:
意外と小さいですね。

2018-01-29 18:40 GMT+09:00 Yosuke Yamamoto <notifications@github.com>:

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

y-yosuke, 2018-01-29:
そうなんですよね．一般の乗用車としては小さいのでそれで良いのかな？と引っかかりを覚えました．

家の車はむしろ最大の大きさ 200mm x 120mm にギリギリ収まるような大きさっぽいので
運転上良好な視界を確保するにはそっちに合わせるのかもしれません．

formula-ppoino では空力的にサイドミラーは悪さをしているので
なるべく小さく，なるべく悪影響の少ない形状にしたいなと思案しているところです．

ミラーレス・カメラ使用が理想的なのかもしれないのですが
コクピットが小さくてドライバサイドのモニターを設置しても
ステアリングホイールや腕に隠れて見えないので難しい感じです．

emijah, 2018-01-30:
ステアリングの斜め上辺りも無理そうですかね？

2018年1月29日 18:50 Yosuke Yamamoto <notifications@github.com>:

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

y-yosuke, 2018-01-30:
見える部分はあるにはあると思いますが，ステアリングを切ったときに腕で見えなくなりそうです．

y-yosuke, 2021-04-02:
自動車の後方確認カメラ、新車の装備義務化　来年５月以降にも - SankeiBiz
http://www.sankeibiz.jp/business/news/210401/bsc2104012245015-n1.htm

y-yosuke, 2022-03-18:
Morgan Super 3 のインテリア

- Shmee150 - I'm BUYING a MORGAN SUPER 3! New Addition to the Shmeemobiles
  - https://www.youtube.com/watch?v=sYndVOxAfKY

emijah, 2022-03-20:
確かにいい！真ん中だから右ハンドルも左ハンドルも同じにできそう。
横にある荷物を入れるバッグのバイクっぽい手軽さも好きです

y-yosuke, 2022-03-20:
可能な限り左右ハンドルは共通設計にしたいですね．

移動用の荷物はハード目のルーフトップキャリアにしてマクロスのストライクバルキリーみたいなマッチョデザインも良いかと思っていましたが，ソフト目のバッグを引っ掛けるのも良いですね．

＜参考＞
- VF-1S ストライクバルキリー ファイター 一条輝 機
  - https://www.hobby-wave.com/products/mc064/

y-yosuke, 2022-03-27:
Aston Martin Valkyrie は 2 dgrees シートが内向きになっていると聞こえるが，英語リスニング怪しい私．
ちなみに formula-ppoino は 3 degrees ．

- WORLD’S FASTEST Convertible! New Aston Martin Valkyrie Spider
  - https://youtu.be/52U1gV_7n6U?t=474

y-yosuke, 2022-03-27:
字幕つけたら良いだけだった． https://youtu.be/52U1gV_7n6U?t=480

y-yosuke, 2022-06-01:
Pedal position adjuster

- FIRST LOOK: Mercedes-AMG One - 1063hp Hypercar With F1 Engine Is FINALLY Finished! | Top Gear
  - https://youtu.be/Lyl-Yt7PBPo?t=846

y-yosuke, 2022-08-18:
- 自動車のタッチパネル操作は物理ボタンの4倍時間がかかる
  - https://gigazine.net/news/20220818-car-touch-screen-physical-button/

y-yosuke, 2022-11-17:
Mclaren Elva はヘルメット収納がついている．（スクーターみたい）

- World First: McLaren Elva - Detailing & Protection!
  - https://youtu.be/vj9rTc5tBEk?t=1262

y-yosuke, 2023-06-15:
- 3.4インチ円形タッチスクリーンディスプレイ（800 x 800, MIPI DSI接続) - SwitchScience
  - https://www.switch-science.com/products/9028
  - "有効表示サイズ：直径3.4インチ（87.6 mm）"

y-yosuke, 2023-08-14:
- 2.1-Inch Round Display with Magnetic Encoder Knob
  - https://www.youtube.com/watch?v=5jDzeOtMlGc

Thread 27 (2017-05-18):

Rr Suspension

y-yosuke, 2017-05-18:
- Bump Steer Angle
  - Stroke Z+50mm : 0.538 deg Toe In
  - Stroke Z-50mm : 0.6817 deg Toe Out

大きすぎるな．

y-yosuke, 2017-05-18:
Track Rod Outer Joint on Upright +40mm ( Horizontal Track Rod )

- Bump Steer Angle
  - Stroke Z+50mm :
  - Stroke Z-50mm :

y-yosuke, 2017-05-18:
Track Rod Outer Joint on Upright Origin +20mm

- Bump Steer Angle
  - Stroke Z+50mm :

y-yosuke, 2017-05-18:
Track Rod Outer Joint on Upright Z+25mm from Origin

- Bump Steer Angle
  - Stroke Z+50mm : 0.0936 deg Toe Out
  - Stroke Z-50mm : 0.0782 deg Toe In

y-yosuke, 2017-05-18:
Track Rod Outer Joint on Upright Z+22mm from Origin

- Bump Steer Angle
  - Stroke Z+50mm : 0.0160 deg Toe Out
  - Stroke Z-50mm : 0.0153 deg Toe Out

Best?

emijah, 2017-05-18:
おおおお

2017-05-18 17:05 GMT+09:00 Yosuke Yamamoto <notifications@github.com>:

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

y-yosuke, 2017-06-13:
Geometry Plan New-B : Upper Wishbone / Upright Point =  20mm Inward

- Bump Steer Angle
  - Stroke Z+50mm : 0.0096 deg Toe In
  - Stroke Z-50mm : 0.0095 deg Toe Out

Ice Color : Recent Origin
Black Color : Plan New-B
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

Recent Origin seems better in the roll center ( Hign and Narrow ).

y-yosuke, 2017-06-13:
Geometry Plan New-C : Upper Wishbone / Upright Point = 20mm outer from Recent Origin

- Bump Steer
  - Stroke Z+50mm : 0.0396 deg Toe Out
  -  Stroke Z-50mm : 0.0202 deg Toe Out

Ice Color : Recent Origin
Lavender Color : Plan New-C
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

Recent Origin is the best in the roll center (Narrow Movement).

y-yosuke, 2017-06-13:
（なんか「たまたまそこがツボ」的に Recent Origin Geometry がベスト...）

y-yosuke, 2017-06-13:
or... is it just a local optimum?

y-yosuke, 2017-06-13:
Upper Wishbone のボルトがバンプストローク（Z+50mm）の時に Rr Fender に干渉するから
ポイントを少しずらして更に Better Geometry をと思って検討したけど，目論見が外れる... orz
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

y-yosuke, 2017-06-13:
やはり Rr Fender 側でなんとかするしかないか...

y-yosuke, 2017-06-15:
Spherical / Rodend Angle

- Lwr Wishbone Inner : 12.0613 deg

y-yosuke, 2017-06-21:
Dimple on Rr Fender for NAS Bolt - Rr Upper Wishbone / Rr Upright
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

y-yosuke, 2021-09-01:
Insights into bump-stop tuning
https://www.vehicledynamicsinternational.com/features/insights-into-bump-stop-tuning.html

y-yosuke, 2022-08-18:
- ホイールストロークhttps://www.weblio.jp/content/%E3%83%9B%E3%82%A4%E3%83%BC%E3%83%AB%E3%82%B9%E3%83%88%E3%83%AD%E3%83%BC%E3%82%AF
  - "一般の乗用車では通常150～200mmくらいである。"

現在前後とも ±50mm でストローク 100mm で設計しているが... 短いのか？

y-yosuke, 2022-09-18:
スフェリカルは結構大きいものを使っているように見える．

- Revealing the engineering secrets behind the Aston Martin Valkyrie - Words: Jonathan Bell
  - https://magazine.astonmartin.com/design/revealing-engineering-secrets-behind-aston-martin-valkyrie

y-yosuke, 2023-05-02:
- 世界初 常識外の挙動を実現する力学的非対称ゲル 理研が開発【橋本幸治の理系通信】- テレ東BIZ
  - https://txbiz.tv-tokyo.co.jp/txn/kaisetsu/post_273332

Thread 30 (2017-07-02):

Front Bodywork

y-yosuke, 2017-07-02:
- Flap angle adjuster
  - -10 to 10 deg
  - Adjuster Stroke about : 20 mm / 10 deg = 2 mm/deg
  - Adjuster Screw : M6x1.0 -> 1 turn = Adjuster Stroke 1mm = Flap angle 0.5 deg

y-yosuke, 2017-07-05:
別添99 歩行者頭部及び脚部保護の技術基準
http://www.mlit.go.jp/common/000193252.pdf

Monocoque および Nose Cone の該当部分全体をボンネットもしくは二重構造にして緩衝空間を設けた方が良さそう．

y-yosuke, 2018-01-01:
Fr Wing Flap の角度がきついところの流れが剥離しているようなのでスリットを設けて対策．
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

要CFD

y-yosuke, 2018-01-01:
Slit 有無比較 GIFアニメ
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

y-yosuke, 2022-10-05:
Front Number Plate aft corn? shroud? garnish?

- $3M ASTON MARTIN VALKYRIE Arrives at Topaz London! 1st UK Customer Car
  - https://youtu.be/mKZbv78UR4k?t=352

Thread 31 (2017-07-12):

CFD Rear Bodywork on SimScale

y-yosuke, 2017-07-12:

y-yosuke, 2017-07-14:
fp-023d - Rear Bodywork @ SimScale
https://www.simscale.com/projects/yosukegb4/fp-023d_-_control_1/

y-yosuke, 2017-07-14:
Google Calc : Coefficients Comparison fp-023d for GitHub Issues
https://docs.google.com/spreadsheets/d/1j4ySBqmNtPsV2u_0bn1lc_qqCUI9dESTD_0UFHFbY3c/edit#gid=0

y-yosuke, 2017-07-14:
### Remesh and Recalc fp-023d Control Comparison

All calculations below are CFD using the same car body shape and posture of 'Fr Fender Louver C + Louver Stay B'.

- Control (Aug 2016) : fp-023c - Front Aero Devices / Simulation - fp-023c - Fr Fender Louver C Louver Stay B
  - https://www.simscale.com/workbench/?pid=3781955060523638359#tab_1-0
- Recalc (Jul 2017) : Re-calculated result using the mesh of Control (aug 2016)
- Remash (Jul 2017) : Remesh the STL data newly exported the same CAD model of 'Fr Fender Louver C + Louver Stay B' and recalc the mesh

Have any CFD simulation conditions changed???

Body and Wheels : Fr Fender Louver C + Louver Stay B

Coef.	|	Control (Aug 2016)	|	Difference	|	Recalc (Jul 2017)	|	Difference	|	Remesh  (Jul 2017)	|	Remarks
---	|	---	|	---	|	---	|	---	|	---	|	---
Cm	|	0.0496	|	0.0013	|	0.0509	|	-0.0006	|	0.0503	|
Cd	|	0.5622	|	0.0626	|	0.6248	|	0.0006	|	0.6253	|
Cl	|	-0.1990	|	0.0161	|	-0.1828	|	0.0003	|	-0.1825	|
Clf	|	-0.0499	|	0.0094	|	-0.0406	|	-0.0004	|	-0.0409	|
Clr	|	-0.1490	|	0.0068	|	-0.1423	|	0.0007	|	-0.1415	|
CoP	|	0.7491	|	0.0291	|	0.7782	|	-0.0025	|	0.7756	|
L/D	|	-0.3539	|	0.0613	|	-0.2926	|	0.0008	|	-0.2918	|

Body Only Fr Fender Louver C + Louver Stay B

Coef.	|	Control (Aug 2016)	|	Difference	|	Recalc (Jul 2017)	|	Difference	|	Remesh  (Jul 2017)	|	Remarks
---	|	---	|	---	|	---	|	---	|	---	|	---
Cm	|	0.0300	|	0.0010	|	0.0310	|	-0.0004	|	0.0306	|
Cd	|	0.4401	|	0.0240	|	0.4640	|	0.0000	|	0.4641	|
Cl	|	-0.2515	|	0.0585	|	-0.1931	|	0.0008	|	-0.1923	|
Clf	|	-0.0958	|	0.0303	|	-0.0655	|	0.0000	|	-0.0656	|
Clr	|	-0.1557	|	0.0282	|	-0.1275	|	0.0008	|	-0.1268	|
CoP	|	0.6192	|	0.0414	|	0.6606	|	-0.0014	|	0.6591	|
L/D	|	-0.5716	|	0.1555	|	-0.4161	|	0.0016	|	-0.4144	|

y-yosuke, 2017-07-14:
I checked the CFD simulation conditions 1 by 1, but I could not find any differences.

y-yosuke, 2017-07-14:
Solver Log

Control (Aug 2016)
```
ExecutionTime = 9447.2 s  ClockTime = 9489 s
forces forces00 output:
    sum of forces:
        pressure : (193.594173988 -212.110703092 -75.7760171924)
        viscous  : (17.3917652795 -1.08442962181 1.11069449078)
        porous   : (0 0 0)
    sum of moments:
        pressure : (89.2308128353 39.431771951 87.3466997841)
        viscous  : (-0.291788799091 9.8484672478 11.4303927196)
        porous   : (0 0 0)
forceCoeffs forceCoeffs02 output:
    Cm    = 0.0299764568244
    Cd    = 0.440050754546
    Cl    = -0.251531019826
    Cl(f) = -0.0957890530888
    Cl(r) = -0.155741966738
forceCoeffs forceCoeffs01 output:
    Cm    = 0.0495514285929
    Cd    = 0.562189539161
    Cl    = -0.198951946782
    Cl(f) = -0.049924544798
    Cl(r) = -0.149027401984
End
Finalising parallel run
```
Recalc (Jul 2017)
```
ExecutionTime = 9234.12 s  ClockTime = 9330 s
forces forces00 output:
    sum of forces:
        pressure : (189.281026352 -196.252364887 -72.8171329932)
        viscous  : (45.1944284719 -3.21975993178 4.20380348382)
        porous   : (0 0 0)
    sum of moments:
        pressure : (92.3956264237 24.053322206 89.8511498638)
        viscous  : (-1.06376364958 26.5247248955 29.0178772838)
        porous   : (0 0 0)
forceCoeffs forceCoeffs02 output:
    Cm    = 0.031001740487
    Cd    = 0.464048885949
    Cl    = -0.193073503032
    Cl(f) = -0.065535011029
    Cl(r) = -0.127538492003
forceCoeffs forceCoeffs01 output:
    Cm    = 0.0508563783388
    Cd    = 0.624779302117
    Cl    = -0.182825908831
    Cl(f) = -0.0405565760767
    Cl(r) = -0.142269332754
End
Finalising parallel run
```

Remesh (Jul 2017)
```
ExecutionTime = 8022.43 s  ClockTime = 8094 s
forces forces00 output:
    sum of forces:
        pressure : (189.499706774 -196.431722066 -72.6679161092)
        viscous  : (45.1896596016 -3.22240724966 4.18000960119)
        porous   : (0 0 0)
    sum of moments:
        pressure : (92.5310074026 23.5012409058 89.6205071841)
        viscous  : (-1.05549639158 26.5240747388 29.015966035)
        porous   : (0 0 0)
forceCoeffs forceCoeffs02 output:
    Cm    = 0.0306025076852
    Cd    = 0.464068604351
    Cl    = -0.192320230353
    Cl(f) = -0.0655576074912
    Cl(r) = -0.126762622862
forceCoeffs forceCoeffs01 output:
    Cm    = 0.0503006051981
    Cd    = 0.625349287192
    Cl    = -0.182491708838
    Cl(f) = -0.0409452492211
    Cl(r) = -0.141546459617
End
Finalising parallel run
```

y-yosuke, 2017-07-14:
Convergence plot curve comparison

Control (Aug 2016)
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

Recalc (Jul 2017)
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

Remesh (Jul 2017)
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

y-yosuke, 2017-07-14:
Hmm..., the convergence curves have changed from Aug 2016 too.

y-yosuke, 2017-07-17:
Anyway comparing Recalc (Jul 2017) with Remesh (Jul 2071), it seems accurate enough.

y-yosuke, 2017-07-18:
### Iteration number and convergence

N=800 is not enough. N=1000 is needed at least, or more iterations?

Rr fender for Tire Stroke		
		
Body and Wheels

Coef.	|	N=800	|	N=1000	|	Difference	|	Difference %	|	Remarks
---	|	---	|	---	|	---	|	---	|	---
Cm	|	0.0464	|	0.0451	|	-0.0013	|	-2.9	|
Cd	|	0.6238	|	0.6242	|	0.0004	|	0.1	|
Cl	|	-0.1741	|	-0.1696	|	0.0046	|	-2.6	|
Clf	|	-0.0406	|	-0.0397	|	0.0009	|	-2.3	|
Clr	|	-0.1335	|	-0.1299	|	0.0036	|	-2.7	|
CoP	|	0.7667	|	0.7660	|	-0.0007	|	-0.1	|
L/D	|	-0.2792	|	-0.2716	|	0.0075	|	-2.7	|

Body Only

Coef.	|	N=800	|	N=1000	|	Difference	|	Difference %	|	Remarks
---	|	---	|	---	|	---	|	---	|	---
Cm	|	0.0306	|	0.0272	|	-0.0034	|	-11.1	|
Cd	|	0.4641	|	0.4687	|	0.0046	|	1.0	|
Cl	|	-0.1923	|	-0.1826	|	0.0097	|	-5.1	|
Clf	|	-0.0656	|	-0.0641	|	0.0015	|	-2.3	|
Clr	|	-0.1268	|	-0.1185	|	0.0083	|	-6.5	|
CoP	|	0.6591	|	0.6491	|	-0.0101	|	-1.0	|
L/D	|	-0.4144	|	-0.3896	|	0.0249	|	-6.0	|

Convergence Plot

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

Force Coefficients Plot

Body and Wheels Coefficients

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

Body Coefficients

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

y-yosuke, 2017-07-18:
### Rr Fender with the wheelhouse for the tire stroke and Side Pod Mod

On rear wheel the downforce decreases or the lift force increases.

Rr fender for Tire Stroke (N=800) / Control : Remesh (Jul 2017)

Body and Wheels

Coef.	|	Control	|	Rr Fender for Tire Stroke	|	Difference	|	Difference %	|	Remarks
---	|	---	|	---	|	---	|	---	|	---
Cm	|	0.0503	|	0.0464	|	-0.0039	|	-7.7	|
Cd	|	0.6253	|	0.6238	|	-0.0015	|	-0.2	|
Cl	|	-0.1825	|	-0.1741	|	**+0.0083**	|	+4.6	|
Clf	|	-0.0409	|	-0.0406	|	+0.0003	|	+0.8	|
Clr	|	-0.1415	|	-0.1335	|	**+0.0080**	|	+5.7	| Decleace in Rr Downforce
CoP	|	0.7756	|	0.7667	|	-0.0089	|	-0.9	|
L/D	|	-0.2918	|	-0.2792	|	+0.0127	|	+4.3	|

Body Only

Coef.	|	Control	|	Rr Fender for Tire Stroke	|	Difference	|	Difference %	|	Remarks
---	|	---	|	---	|	---	|	---	|	---
Cm	|	0.0310	|	0.0306	|	-0.0004	|	-1.3	|
Cd	|	0.4640	|	0.4641	|	+0.0000	|	+0.0	|
Cl	|	-0.1931	|	-0.1923	|	+0.0008	|	+0.4	|
Clf	|	-0.0655	|	-0.0656	|	-0.0000	|	-0.0	|
Clr	|	-0.1275	|	-0.1268	|	**+0.0008**	|	+0.6	| Almost the same
CoP	|	0.6606	|	0.6591	|	-0.0014	|	-0.1	|
L/D	|	-0.4161	|	-0.4144	|	+0.0016	|	+0.4	|

y-yosuke, 2017-07-18:
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
y-yosuke, 2017-07-24:
Side Mirrorless - Flow and Pressure Comparison

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

y-yosuke, 2017-07-24:
### Side Mirror - 30mm Higher and 20mm Outer

Side Mirror - 30mm Higher and 20mm Outer / Control : Rr Bonnet Horizontal Vane

Body and Wheels

Coef.	|	Control	|	Side Mirror - 30mm Higher & 20mm Outer	|	Difference	|	Difference %	|	Remarks
---	|	---	|	---	|	---	|	---	|	---
Cm	|	0.0435	|	0.0436	|	0.0001	|	0.1	|
Cd	|	0.6223	|	0.6229	|	0.0006	|	0.1	|
Cl	|	-0.1842	|	-0.1819	|	0.0022	|	-1.2	|
Clf	|	-0.0486	|	-0.0474	|	0.0012	|	-2.4	|
Clr	|	-0.1356	|	-0.1345	|	0.0011	|	-0.8	|
CoP	|	0.7362	|	0.7394	|	0.0032	|	0.3	|
L/D	|	-0.2960	|	-0.2921	|	0.0039	|	-1.3	|

Body Only

Coef.	|	Control	|	Side Mirror - 30mm Higher & 20mm Outer	|	Difference	|	Difference %	|	Remarks
---	|	---	|	---	|	---	|	---	|	---
Cm	|	0.0253	|	0.0256	|	0.0002	|	1.0	|
Cd	|	0.4676	|	0.4685	|	0.0008	|	0.2	|
Cl	|	-0.1981	|	-0.1959	|	0.0022	|	-1.1	|
Clf	|	-0.0737	|	-0.0724	|	0.0013	|	-1.8	|
Clr	|	-0.1243	|	-0.1235	|	0.0008	|	-0.7	|
CoP	|	0.6277	|	0.6304	|	0.0027	|	0.3	|
L/D	|	-0.4235	|	-0.4182	|	0.0054	|	-1.3	|

y-yosuke, 2017-07-24:
#### Side Mirror 30mm Higher 20mm Outer - Flow and Pressure Comparison

Flow Comparison - Side View / GIF Animation
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

Pressure Comparison - Top View
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

y-yosuke, 2017-07-24:
## Rr Wing

### Rr Wing - 1 piece 50mm Higher

Rr Wing 1pc 50mm Higher / Control : Rr Bonnet Horizontal Vane

Body and Wheels

Coef.	|	Control	|	Rr Wing 1pc 50mm Higher	|	Difference	|	Difference %	|	Remarks
---	|	---	|	---	|	---	|	---	|	---
Cm	|	0.0435	|	0.0487	|	0.0052	|	11.9	|
Cd	|	0.6223	|	0.6255	|	0.0032	|	0.5	|
Cl	|	-0.1842	|	-0.1870	|	-0.0028	|	1.5	|
Clf	|	-0.0486	|	-0.0448	|	0.0038	|	-7.8	|
Clr	|	-0.1356	|	-0.1422	|	-0.0066	|	4.9	|
CoP	|	0.7362	|	0.7603	|	0.0241	|	2.4	|
L/D	|	-0.2960	|	-0.2990	|	-0.0030	|	1.0	|

y-yosuke, 2017-07-24:
#### Rr Wing - 1 Piece 50mm Higher - Flow and Pressure Comparison

Center Flow Comparison / GIF Animation
Line Pitch : 20mm
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

Line Pitch : 10mm
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

y-yosuke, 2017-07-27:
### Rr Wing - 1 Piece and 2 Pieces

- **2 pcs Control** : Rr Wing Main 1.4 Flap 1.3 32.7deg
- **2 pcs -5 deg** : Rr Wing -5deg / Main 1.4 Flap 1.3
- **2 pcs -10 deg** : Rr Wing -10deg / Main 1.4 Flap 1.3
- **1 pc Z+50mm** : Rr Wing 1pc 50mm Higher

Body and Wheels							

Coef. | 2 pcs Control | 2 pcs -5deg | 2 pcs -10deg	| 1 pc Z+50mm | Remarks
--- |	--- | --- | --- | --- | ---
Cm	|	0.1099	|	0.1144	|	0.1020	|	0.0487	|
Cd	|	0.6641	|	0.6575	|	0.6483	|	**0.6255**	|
Cl	|	-0.3098	|	**-0.3142**	|	-0.2883	|	-0.1870	|
Clf	|	**-0.0450**	|	-0.0427	|	-0.0421	|	**-0.0448**	|
Clr	|	-0.2648	|	**-0.2715**	|	-0.2462	|	-0.1422	|
CoP	|	0.8548	|	0.8641	|	0.8538	|	**0.7603**	|
L/D	|	-0.4666	|	**-0.4779**	|	-0.4447	|	-0.2990	|

Body Only

Coef. | 2 pcs Control | 2 pcs -5deg | 2 pcs -10deg | 1 pc Z+50mm | Remarks
---	| --- | --- | --- | --- | ---
Cm	|	0.0909	|	0.0954	|	0.0834	|	0.0307	|
Cd	|	0.5030	|	0.4971	|	0.4896	|	**0.4711**	|
Cl	|	-0.3234	|	**-0.3280**	|	-0.3021	|	-0.2008	|
Clf	|	**-0.0708**	|	-0.0686	|	-0.0677	|	-0.0697	|
Clr	|	-0.2526	|	**-0.2594**	|	-0.2344	|	-0.1311	|
CoP	|	0.7810	|	0.7909	|	0.7759	|	**0.6528**	|
L/D	|	-0.6430	|	**-0.6597**	|	-0.6170	|	-0.4263	|

y-yosuke, 2017-07-27:
#### Rr Wing - 1 Piece and 2 Pieces / Flow Comparizon - Wing and Diffuser

Flow Comparison - GIF Animation
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

Each Still Images
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

y-yosuke, 2017-07-27:
#### Rr Wing - 1 Piece and 2 Pieces / Flow Comparizon - Wing

Flow Comparison - GIF Animation

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

Each Still Images

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

y-yosuke, 2017-07-27:
Rr Wing - 1 Piece and 2 Pieces / U Magnitude Comparizon - Wing

Flow Comparison - GIF Animation

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

Each Still Images

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

y-yosuke, 2017-07-27:
### Rr Wing Flap Angle

Rr Wing -5deg / Main 1.4 Flap 1.3 27.7deg (-5deg)
Control : Rr Wing -5deg / Main 1.4 Flap 1.3 (37.7deg)

Body and Wheels

Coef. | Control |  Rr Wing Flap -5deg | Difference | Difference % | Remarks
---	|	---	|	---	|	---	|	---	|	---
Cm	|	0.1144	|	0.1087	|	-0.0057	|	-5.0	|
Cd	|	0.6575	|	0.6533	|	-0.0042	|	-0.6	|
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

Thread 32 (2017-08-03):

Fr Bonnet for Crush Space on Monocoque and Nose Cone

y-yosuke, 2017-08-03:
歩行者頭部保護を目的とした衝撃吸収空間を設けるために Front Bonnet を Monocoque および Nose Cone 上に設置することを考える．

どのくらいの空間があれば，またはどのような積層断面にしたら十分な効果があるかは分らないが，
ひとまず描いてみる．

- Surface Offset : -55mm = about Space of 50mm

y-yosuke, 2017-08-03:
攻めずに無駄に大きいモノコックにしておいたのが功を奏したかな？

- 足部などの空間は大丈夫そう
- Steering Shaft を通すところが狭くなりそう

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

y-yosuke, 2017-08-05:
Nose Cone and Monocoque with 55mm Offset Upper Surface for Crush Space
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

y-yosuke, 2017-08-09:
パーツ割り
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

y-yosuke, 2017-08-09:
Fr Damper Cover を外したとき Top View
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

y-yosuke, 2017-08-11:
Fr Bonnet パーティングラインの変更（前の方を上方に浅く）
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

y-yosuke, 2017-08-11:
Fr Damper Cover の廃止 ← 型割りが大量発生しそうなのでパーツ構成を見直し
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

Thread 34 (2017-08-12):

CFD - Number Plate / Fr Wing

y-yosuke, 2017-08-12:
Control : Side Mirror - 30mm Higher & 20mm Outer

Body and Wheels

Coef. | Control | Number Plate - UK | Number Plate - UK / Fr Wing - Curved Center Z-40mm | Remarks
---	| --- | --- | --- | ---
Cm	| 0.0436 | 0.0444 | 0.0475 |
Cd	| 0.6229 | 0.6271 | 0.6272 |
Cl	| -0.1819 | -0.1531 | -0.1406 |
Clf	| -0.0474 | -0.0321 | -0.0228 |
Clr	| -0.1345 | -0.1210 | -0.1179 |
CoP	| 0.7394 | 0.7902 | 0.8382 |
L/D	| -0.2921	| -0.2442	| -0.2242	|

Body Only

Coef. | Control | Number Plate - UK | Number Plate - UK / Fr Wing - Curved Center Z-40mm | Remarks
---	| --- | --- | --- | ---
Cm	|	0.0256	|	0.0228	|	0.0272	|
Cd	|	0.4685	|	0.4802	|	0.4779	|
Cl	|	-0.1959	|	-0.1723	|	-0.1584	|
Clf	|	-0.0724	|	-0.0634	|	-0.0520	|
Clr	|	-0.1235	|	-0.1089	|	-0.1063	|
CoP	|	0.6304	|	0.6321	|	0.6715	|
L/D	|	-0.4182	|	-0.3589	|	-0.3314	|

y-yosuke, 2017-08-12:
#### Number Plate - Flow Comparison

Flow around car center

GIF Animation

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

Each Still Images

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

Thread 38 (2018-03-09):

[CFD] Side Pod / Radiator

y-yosuke, 2018-03-09:
Radiator CFD Model として Porous Media を設定したいが
そのための cellZone 有りのメッシュ作成に失敗するので
単純な多孔モデルとしてみる．

- Radiator - Control : 126 Holes (14x9)
  - 20mm x 20mm Square Holes / 30mm Pitch / Length 35mm
  - Duct : Area = 120523.294 (+/- 0.00023) square millimeters
  - Not Hole : Area = 70123.2943 (+/- 0.00023) square millimeters
  - Opening 41.8% : (120523.294-70123.2943)/120523.294 = 0.41817642073
- Radiatro - Control : 504 Holes (28x18)
  - 10mm x 10mm Square Holes / 15mm Pitch / Length 35mm
  - Duct : Area = 120523.294 (+/- 0.00023) square millimeters
  - Not Hole : Area = 70123.2943 (+/- 0.00023) square millimeters
  - Opening 41.8% : (120523.294-70123.2943)/120523.294 = 0.41817642073

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

y-yosuke, 2018-03-09:
Mesh around the radiator in "Mesh - fp-024a - Control / Radiator Holes"
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

y-yosuke, 2018-03-10:
- Radiator Holes
  - Radiator Section Flow : 0.172154

y-yosuke, 2018-03-11:
Mesh around the radiator in  "Mesh - fp-024a - Control / Radiator Holes - 10mm x 10mm"
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

y-yosuke, 2018-03-12:
- Sidepod Control - C / Radiator Flow Comparison
  - Control Sidepod / Radiator Holes 10mm x 10mm - 28x18 : 0.13570  [m^3/s]
  - Sidepod C / Radiator Holes 10mm x 10mm - 28x20 : 0.15506 [m^3/s]

emijah, 2018-03-13:
どうしても大きめな穴になってしまうということですね？三角はダメですかね？

y-yosuke, 2018-03-13:
メッシュを細かくしたら穴は小さくできると思いますが
20mm x 20mm と 10mm x 10mm では車両全体の空力性能値にあまり違いが出なかったので
10mm x 10mm ぐらいでとりあえずデバイス比較をしようかと考えています．

四角いのは SimScale の CFD メッシュが Hex Mesh なので
少ないメッシュで小さな穴が作成できるかと思いそうしています．

- Radiator Holes 10mm x 10mm
  - Control : Radiator Holes 20mm x 20mm

Body and Wheels

Coef.	|	Control	|	Radiator Holes 10mm x 10mm	|	Difference	|	Difference %	|	Remarks
---	|	---	|	---	|	---	|	---	|	---
Cm	|	0.0353	|	0.0356	|	0.0003	|	0.9	|
Cd	|	0.5637	|	0.5638	|	0.0000	|	0.0	|
Cl	|	-0.1810	|	-0.1806	|	0.0004	|	-0.2	|
Clf	|	-0.0552	|	-0.0547	|	0.0005	|	-0.9	|
Clr	|	-0.1258	|	-0.1259	|	-0.0002	|	0.1	|
CoP	|	0.6950	|	0.6973	|	0.0022	|	0.2	|
L/D	|	-0.3210	|	-0.3203	|	0.0007	|	-0.2	|

Body Only

Coef.	|	Control	|	Radiator Holes 10mm x 10mm	|	Difference	|	Difference %	|	Remarks
---	|	---	|	---	|	---	|	---	|	---
Cm	|	0.0101	|	0.0104	|	0.0003	|	3.3	|
Cd	|	0.4548	|	0.4548	|	0.0000	|	0.0	|
Cl	|	-0.2190	|	-0.2188	|	0.0002	|	-0.1	|
Clf	|	-0.0994	|	-0.0990	|	0.0004	|	-0.4	|
Clr	|	-0.1196	|	-0.1198	|	-0.0002	|	0.2	|
CoP	|	0.5461	|	0.5476	|	0.0016	|	0.2	|
L/D	|	-0.4815	|	-0.4811	|	0.0005	|	-0.1	|

Also see Google Drive file :
https://docs.google.com/spreadsheets/d/1zDkpTxiz5o6DTmW6s7C5rSQ0SUoApb7MKp-XtCqKJaE/edit#gid=0

y-yosuke, 2018-03-14:
SimScale の Forum を見ると cellZone の作成失敗の件が多いからもしかして中の問題なのか？？？
https://www.simscale.com/forum/

y-yosuke, 2018-03-21:
（計算結果が貯まっていくばかりで... あぁ... まとめないと... 忘れる前にまとめないと...）

emijah, 2018-03-21:
:D ぜひ

2018-03-21 19:19 GMT+09:00 Yosuke Yamamoto <notifications@github.com>:

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

y-yosuke, 2018-03-21:
SimScale のリンクをまだ貼っていなかった．
fp-024a - Sidepod / Radiator
https://www.simscale.com/workbench/?pid=4135868279315342050#tab_0-0

y-yosuke, 2018-03-23:
## fp024a - Sidepod / Radiator Study

This study is based on simulations as in below.

- Fp-023d - Rear Bodywork Study
  - Forum : https://www.simscale.com/forum/t/fp-023d-rear-bodywork-study/76182
  - Project : https://www.simscale.com/workbench/?pid=2563999609424123969#tab_0-0
- Fp-

### Contents

y-yosuke, 2018-03-23:
（レポートを書き始めましたので頻繁に過去の投稿を編集します）

y-yosuke, 2018-03-23:
もとい，Wiki ページでレポートを編集します．
https://github.com/y-yosuke/formula-ppoino/wiki/fp024a---Sidepod---Radiator-Study

y-yosuke, 2018-03-24:
Images of Simulation "Model with Updates"
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

y-yosuke, 2018-03-25:
Radiator Models
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

y-yosuke, 2018-03-25:
Sidepod C & Radiator Duct C Difference Images
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

y-yosuke, 2018-03-26:
Sidepod C - Louvers
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

y-yosuke, 2018-03-27:
Radiator Flow - U Magnitude
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

emijah, 2018-03-27:
ラジエータのリア側のダクト部分がカクカクになっているのですが、ここは丸くしてラジエータにもう少し半時計回りに開店させることはできないですかね？

2018-03-27 15:20 GMT+09:00 Yosuke Yamamoto <notifications@github.com>:

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

emijah, 2018-03-27:
NACAダクトのみでラジエータに空気を送るのはさすがに流量が少なすぎてダメですかね？

2018-03-27 15:44 GMT+09:00 Hajime Saito <emijah.s@gmail.com>:

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

y-yosuke, 2018-03-27:
@emijah フィレット形状のことでしょうか？
Sidepod C - Radiator Duct D / Turning Fillet

また，ラジエタのレイアウトは配管のことも考慮してモノコックに近すぎないようにしています．

y-yosuke, 2018-03-27:
NACAダクト風は 1994年の Ferrari 412T がありますが，
この形状は冷却に問題があり第5戦からコンベンショナルな形状に変わっています．

Ferrari 412T 初期バージョン
http://www.motorsportretro.com/2014/06/photo-of-the-day-1994-ferrari-412t/

https://ja.wikipedia.org/wiki/%E3%83%95%E3%82%A7%E3%83%A9%E3%83%BC%E3%83%AA%E3%83%BB412T1

y-yosuke, 2018-03-27:
今回の fp024a の CFD から流入空気は十分で
アウトレット側の空け方にラジエタ流量が大きく影響されているので
ラジエタダクト入り口の下側や外側にアタッチメントを設けて
CLや  L/D の向上につながる可能性はあります．

こういうの（Radiator Duct の B にはデータを作成していたのですが Duct C と D には未作成）

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

一応，3月中にレポートとして SimScale に投稿したいので今はレポートを書くのを優先しています．

y-yosuke, 2018-03-27:
ラジエタのレイアウトはラジエタ部品により再考の余地はありますが「少しだけ」ですね．

- 上部をどれくらい傾けるか
- 前後位置
- 下後部はモノコックに対して十分近づいているので内側には行かない

お金をかけて非長方形のひし形や曲線外形のラジエタを作るのなら話は別ですが．

y-yosuke, 2018-03-27:
Image of Radiator Duct D / Vertical Turning Fillet / Vertical Turning Vane x1
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

emijah, 2018-03-27:
インボード側にあるダクトの最後端ですよね？空気を曲げるにはRをつけた方が良さそうな感じがするのですが、間違いですかね？

2018-03-27 15:48 GMT+09:00 Yosuke Yamamoto <notifications@github.com>:

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

emijah, 2018-03-27:
あ、しっかりとRがついていますね。失礼しました。

2018-03-27 16:21 GMT+09:00 Yosuke Yamamoto <notifications@github.com>:

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

y-yosuke, 2018-03-27:
Fillet あり/なし も比較しましたが「あり」の方が 1% ほど良いですが，
アウトレットのデバイスの効果にくらべたら誤差程度ですね．

型割り的に Fillet は別部品になると思うので
Fillet なしでも 1% 程度しか悪くならないのであれば無くても良いかなと言う程度と考えています．
競技用ならつけるとは思います．という部品かな...

y-yosuke, 2018-03-27:
ざっというと

- ダクト内の改善効果 : 0〜3%
- アウトレットの改善効果 : 20〜50%

なので，現状の設計では流入側はサチっていて
空力的悪影響の少ない流出側の確保がラジエタ流量の向上する場合には必要と考えています．

（2000年代前半に多い「チムニー」はあまり好きではないので設計していない）

y-yosuke, 2018-03-27:
間違えた．逆でした．
"Fillet あり/なし も比較しましたが「あり」の方が 0.3% 流量が少ない"

なので Fillet は無しですね．

y-yosuke, 2018-03-27:
（ラジエタのモデリングが適切か？という問題もあるんだけど... そこらは風洞や実車との比較で確認して... てなってしまうので，まぁ「アタリ」をつける意味合いの CFD 解析ということで）

emijah, 2018-03-27:
少ないんだ！なんと。

2018-03-27 17:01 GMT+09:00 Yosuke Yamamoto <notifications@github.com>:

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

emijah, 2018-03-27:
確かにチムニーはいまいちな感じですね。カウルの内側にNACAダクトは吸い出しに効くのだろうか？

2018年3月27日 16:51 Yosuke Yamamoto <notifications@github.com>:

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

y-yosuke, 2018-03-27:
@emijah そうなんですよ．誤差の誤差程度に少なかったんですよ．
なのでラジエタモデルにも依存しそうなぐらいの差ですし，まぁ今のとこと Fillet 無しで良いかなと．
検討は風洞や実車との相関が得られてからでも遅くないと思います．

y-yosuke, 2018-03-27:
吸い出しNACA風ダクトは 90年代初頭 に流行ったように思います．
イメージしているのとは逆方向かもしれませんが．
https://ja.wikipedia.org/wiki/%E3%83%95%E3%82%A1%E3%82%A4%E3%83%AB:Ayrton_Senna_1992_Monaco.jpg
http://motor.geocities.jp/formura1_model/F92ATkit.html

y-yosuke, 2018-03-27:
NACA Duct はある程度流体の運動エネルギーがあるところでないと効果が薄いイメージです．

y-yosuke, 2018-03-27:
NACA Duct が有効に働く条件が NACA の NACA Duct のレポートに書いてあったと思います．

y-yosuke, 2018-03-27:
Radiator Duct C も D も大して変わらないから Intake Adjustor Panel は C ので計算する．

y-yosuke, 2018-03-27:
（追加計算はネタ的にそのまますぎるので中止）

emijah, 2018-03-28:
NACA
ductを逆向きに使用する例はかなりありますが、なんとなく裏返しな感じがしてしまうんですよね。吸い出しにサメのエラのようなルーバーを使うケースが多いですが、なんとなく見た目だけな気がしてしまうんですよね。exhaust
ductについてちょっと調査してみます。

2018-03-28 0:07 GMT+09:00 Yosuke Yamamoto <notifications@github.com>:

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

y-yosuke, 2018-03-28:
Pictures of Radiator Duct C and D
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

y-yosuke, 2018-03-28:
Sidepod C - Pressure / Left View
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

y-yosuke, 2018-03-28:
Sidepod C - Louvers / Pressure Images
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

y-yosuke, 2018-03-28:
Sidepod C - Louvers / U Magnitude at Z=220mm Capture Image
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

emijah, 2018-03-28:
さらにリップをつけると良さそうですね。

2018-03-28 16:58 GMT+09:00 Yosuke Yamamoto <notifications@github.com>:

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

y-yosuke, 2018-03-29:
単なる穴やチムニーだと静止時に雨が入ってくるので
ルーバーでかつリアタイアフェアリングの下に来るのが良いかな．

位置は浸水のことも考えると高い位置のほうが良いし冷却能力が十分であれば
Louver Lwr / Top Half が効率的で良いと考えている．

y-yosuke, 2018-03-29:
（浸水だったら Rr Lwr Wishbone の通る穴が低いではないか．というのはある）

y-yosuke, 2018-03-29:
Turning Fillet
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

Turning Vane - Vertical
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

Turning Vane - Vertical 2 pcs
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

Turning Vane - Horizontal
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

Turning Vane - Horizontal B
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

y-yosuke, 2018-03-29:
とりあえずレポートを一通り書いた．
https://github.com/y-yosuke/formula-ppoino/wiki/%5Bfp024a%5D-Sidepod-Radiator-Study

何時間かしてから読み返して修正して SimScale に投稿する．

y-yosuke, 2018-03-29:
markdown の Table に SimScale が対応していて嬉しい．

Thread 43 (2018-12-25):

[CFD] Windscreens - fp024d

y-yosuke, 2018-12-25:
Now planning windscreens CFD simulations.

*[ ] Original Screen ( AA mm )
*[ ] Hight BB mm ( CC mm higher than the original screen )
*[ ] Low in middle
*[ ] Super 7 like large windscreen

y-yosuke, 2019-01-07:
fp024d - No Windscreen				
				
Coef.	|	Whole Car	|	Body & Head	|	Body	|	Head	|	Fr Wheel	|	Rr Wheel
---	|	---	|	---	|	---	|	---	|	---	|	---
Cm	|	0.0406	|	0.0162	|	0.0147	|	0.0014	|	0.0211	|	0.0034
Cd	|	0.6224	|	0.5131	|	0.5038	|	0.0093	|	0.0483	|	0.0610
Cl	|	-0.1901	|	-0.2289	|	-0.2490	|	0.0200	|	0.0306	|	0.0082
Clf	|	-0.0544	|	-0.0983	|	-0.1098	|	0.0114	|	0.0364	|	0.0075
Clr	|	-0.1357	|	-0.1306	|	-0.1392	|	0.0086	|	-0.0058	|	0.0007
CoP	|	0.7136	|	0.5706	|	0.5592	|	0.4289	|	-0.1892	|	0.0909
L/D	|	-0.3054	|	-0.4461	|	-0.4941	|	2.1524	|	0.6342	|	0.1348
RF	|		|	m<sup>3</sup>/s	|		|		|		|
				
Differences from the Origin
				
Coef.	|	Whole Car	|	Body & Head	|	Body	|	Head	|	Fr Wheel	|	Rr Wheel
---	|	---	|	---	|	---	|	---	|	---	|	---
Cm	|	0.0131	|	0.0138	|	0.0069	|	0.0069	|	-0.0001	|	-0.0006
Cd	|	0.0545	|	0.0567	|	0.0320	|	0.0247	|	-0.0008	|	-0.0014
Cl	|	0.0024	|	0.0014	|	-0.0025	|	0.0039	|	0.0000	|	0.0010
Clf	|	0.0143	|	0.0145	|	0.0057	|	0.0088	|	-0.0001	|	-0.0002
Clr	|	-0.0119	|	-0.0131	|	-0.0082	|	-0.0050	|	0.0001	|	0.0011
CoP	|	0.0708	|	0.0605	|	0.0275	|	-0.4091	|	0.0031	|	0.1434
L/D	|	0.0335	|	0.0585	|	0.0283	|	3.2078	|	0.0111	|	0.0186
RF	|	0.0000	|	m<sup>3</sup>/s	|		|		|		|

y-yosuke, 2019-01-07:
Working on Google Calc.
https://docs.google.com/spreadsheets/d/1KisTdgJNMGy2lwkoOdChzCK5JLjD3UvQDMlo0CT7evw/edit?usp=sharing

y-yosuke, 2019-02-08:
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

y-yosuke, 2019-02-08:
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

y-yosuke, 2019-02-08:
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

y-yosuke, 2019-02-09:
SimScale Link : https://www.simscale.com/workbench/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

y-yosuke, 2019-02-10:
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

y-yosuke, 2019-02-10:
Now Writing GitHub Wiki
https://github.com/y-yosuke/formula-ppoino/wiki/%5Bfp024d%5D-Windscreens

y-yosuke, 2019-02-10:
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

y-yosuke, 2019-02-11:
Streamline Comparison - Front View
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

y-yosuke, 2019-02-11:
Streamline Comparison - Left View Animation
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

y-yosuke, 2019-02-12:
Flow Vector and Pressure around the Head
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

y-yosuke, 2019-02-15:
Cockpit Center Bridge
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

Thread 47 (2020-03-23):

[CFD] Rr Fender

y-yosuke, 2020-03-23:
サイドポッドが高くなったのに伴いリアフェンダー前のデッキ？部分の 50mm 高いバージョン

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

y-yosuke, 2020-05-13:
ジオメトリーデータのチェックが厳しくなって使えなくなったり，アップロードできなくなったりと全然進まない．

y-yosuke, 2020-05-13:
Simulation Menu

- [ ] Control
- [ ] Control - Radiator Louver
- [ ] Rr Fender 50mm Higher Deck
- [ ] Rr Fender 50mm Higher Deck - Fairing Fin
- [ ] Rr Fender 50mm Higher Deck - Fairing Box
- [ ] Rr Fender 50mm Higher Deck - Radiator Louvre

y-yosuke, 2020-06-08:
（サイドディフューザーは今板で終わらせているけど追加したらFr.ダウンフォースも増えるか...）

y-yosuke, 2020-06-08:
（あまりなーフロアでダウンフォースを稼ぐと素人ドライブに適さなくなるような気がしてなぁ... でも「そんなもんダウンフォースを稼げてから言えや」的な考え方もありよなー）

y-yosuke, 2020-08-07:
SimScale がアップロード時のオプション設定インタフェースを追加してくれたので，Rhino-Python でメッシュチェックしたり目視チェックしながら手動でジオメトリメッシュ修正をしたらアップロード＆利用できるようになった．
https://www.simscale.com/workbench/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

y-yosuke, 2020-08-12:
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

y-yosuke, 2020-12-22:
さてと... 冬休みの宿題にしたいところ...

y-yosuke, 2021-03-16:
- Rear Combi Lamps
  - https://www.gregsraceparts.com/products/grp-v3-tail-lights-for-01-elise-exige-02-04-esprit
  - https://www.youtube.com/watch?v=tkTx35Q5P9Y

y-yosuke, 2021-03-23:
冬休みの宿題とか言ってたけど... Simulation Runs は終わっているけどレポート書いてない．
春休みの宿題ぐらいで書き終えたいところ．

y-yosuke, 2021-04-02:
Wiki は作った（だけ）．
https://github.com/y-yosuke/formula-ppoino/wiki/%5Bfp024f%5D-Rear-Fender-Study

y-yosuke, 2021-04-04:
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

y-yosuke, 2021-04-17:
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

y-yosuke, 2021-05-01:
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

y-yosuke, 2021-05-02:
Re-captured images

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

y-yosuke, 2021-05-02:
resized half

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

y-yosuke, 2021-05-02:
gif images

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

y-yosuke, 2021-05-02:
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

y-yosuke, 2021-05-02:
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

y-yosuke, 2021-05-05:
| Fender and Radiator Outlet Types |  Radiator Flow m^3/s |
|  :--- | ---:  |
| Control | 0.1628 |
| Rr Fender 50mm Higher Deck | 0.1620 |
| Rr Fender 50mm Higher Deck + Fin | 0.1620 |
| Rr Fender 50mm Higher Deck + Box | 0.1626 |
| Rr Fender 50mm Higher Deck + Fin + Upper Fence | 0.1913 |
| Control + Radiator Louvre | 0.2447 |
| Rr Fender - 50mm Higher Deck + Radiator Louvre | 0.2358 |

y-yosuke, 2021-05-05:
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

y-yosuke, 2021-05-06:
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

y-yosuke, 2021-05-08:
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

y-yosuke, 2021-05-08:
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

y-yosuke, 2021-05-08:
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

y-yosuke, 2021-05-08:
APNG

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

y-yosuke, 2021-05-08:
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

y-yosuke, 2021-05-08:
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

y-yosuke, 2021-05-09:
- Comparing the 2 models with radiator louvers, "50mm Higher Deck" seems to have a slightly stronger low pressure on the underside of the floor.

y-yosuke, 2021-05-09:
## Summary

- The "50mm Higher Deck" models generally tend to have better aerodynamic performance than the "Control" model.
- The "50mm Higher Deck" model reduces the drop in aerodynamic performance when a radiator outlet louver is installed.
- Among the "50mm Higher Deck" models,
  - "Fin" type increases downforce both front and rear best,
  - "Box" type has the potential for low drag shapes,
  - "Upper Fence" spoils the increase in "Fin" type rear downforce, but increases the radiator flow.

y-yosuke, 2021-05-09:
うわ，この Issue 1年ものじゃないか...

y-yosuke, 2021-05-09:
## Introduction

Since there was room to raise the rear fender deck by 50 mm, I simulated some rear fender models of 50mm higher deck with some aerodynamic devices.

y-yosuke, 2021-05-09:
- GitHub Wiki
  - https://github.com/y-yosuke/formula-ppoino/wiki/%5Bfp024f%5D-Rear-Fender-Study
- Post in SimScale Forum
  - https://www.simscale.com/forum/t/fp024f-rr-fender-study-simulation-project-by-yosukegb4/92683/2?u=yosukegb4

y-yosuke, 2021-05-09:
SimScale Forum では GIF や APNG がちゃんと動作しない場合があるので何とかして直す．

y-yosuke, 2021-05-10:
アニメーション画像 GitHub にアップロードしたファイルをリンク先としている場合は動いているけど SimScale Forum のシステムが外部サイトの画像は SimScale Forum 内の画像として置き換えるとアニメーション PNG が表示されなくなる？？？

y-yosuke, 2021-05-10:
I replaced Animated-PNG files to Animated GIF files < 4MB.

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

y-yosuke, 2021-05-10:
Mac では PicGIF Lite アプリが良いっぽい．

y-yosuke, 2021-05-12:
（1年半ぶりぐらいにレポート投稿したんだけどフォーラムにいる人が替わっている...）

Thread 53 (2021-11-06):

ライセンスの変更 CC の BY-SA から BY に変更したい

y-yosuke, 2021-11-06:
ソースとしてのコントリビュータとしては @y-yossuke のみなので一義的な権利保有は私1名なのですが，ライセンス変更に異議がある場合は本 Issue に投稿願います．

emijah, 2021-11-07:
異議なし

y-yosuke, 2021-11-07:
@emijah ありがとうございます．

y-yosuke, 2021-11-12:
CC-BY へのライセンス変更の PR & Merge して変更を確認しました．

Closed 2021-11-12.

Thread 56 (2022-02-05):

Front Anti Intrusion Panel

y-yosuke, 2022-02-05:
https://twitter.com/ScarbsTech/status/1489970098957918216

y-yosuke, 2022-02-05:
現状空いている穴はそんなに大きくないのでスタビライザーの位置とブラケットが再設計になりそうだけど行けそう．

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

y-yosuke, 2022-02-05:
- [ ] あとはプッシュロッドがモノコック内から見える構造なのでここを筒状に構造を通してしまってプッシュロッドが折れても搭乗者に危害が及ばないようにしたい．

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

y-yosuke, 2022-02-05:
https://github.com/y-yosuke/formula-ppoino/issues/56#issuecomment-1030637575
スタビ周辺はフロントボンネットの S-Duct との干渉に気をつければ他は余裕があるので行けそう（その2）．

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

y-yosuke, 2022-02-21:
Anti intrusion cylinder for fr pushrod

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

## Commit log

2015-10-03 1st CAD data commit
2015-10-29 add STL and STEP files of 1:43 scale model md022.
2016-03-02 mod fr suspension geometry, fr wing-fender, rr fender, rr bumper, rr wing end plate
2016-05-29 mod Fr Wing-Fender, Fr Wing Flap, Monocoque, Rr Fender, Fr Suspension
2016-06-21 mod Rear Bodywork, Monocoque and Cockpit, add Third Brake Light and Radiator Duct Intake Adjustre Panel
2016-07-01 add 1:43 scaled model fp-023 files (STP/STL)
2016-12-05 add step and stl files of fp023c-plus 1:43 scale model for SLS Nylon
2017-03-17 mod Nose Cone and Monocoque for S-Duct, EV Module layout examination
2017-05-04 mod formula-ppoino cad files
2017-06-16 mod / add suspension, upright, steering sys, monocoque, headlight, rr wing, rr fender, rr bumper b, sidpod bad, under panel bad, fire extinguisher and so on.
2017-12-12 changes july to december 2017 / The vehicle model file was divided into each system models.
    [fp_environment.stp, fp_fr_axle_sys.stp, fp_nose_cone_assy.stp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]
2018-04-02 add STL model files for fp024a CFD
2020-04-10 add fp024f cfd model step files and scaled model stp/stl files.
2021-02-14 add mod files
    [fp_fr_fender_mod-20210214.stp]
2021-11-06 mod design of front and rear fender and add zip files of cfd fp024f models
    [fp_fr_fender.stp, fp_fr_fender_mod-20210214.stp, fp_rr_bumper.stp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]
2021-11-12 remove a description about 「継承」.
